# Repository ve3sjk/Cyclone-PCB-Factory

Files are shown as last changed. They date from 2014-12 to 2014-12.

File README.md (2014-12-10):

<p align="center">

<div align="center"><i>A 3D-printable (Rep-Rap alike) CNC machine, intended for PCB manufacture.</i></div>
</p>  

Read this, it's important!
===========================
If you are reading this, then you are looking at the development version of Cyclone PCB Factory.
This means files may present inconsistencies (dimensions mismatch, lack of tolerances, etc).
If you just want to build the machine, take a look at the following locations:

- **Releases: <https://github.com/carlosgs/Cyclone-PCB-Factory/releases>**
- **Documentation: <http://reprap.org/wiki/Cyclone_PCB_Factory>**

<p align="center">
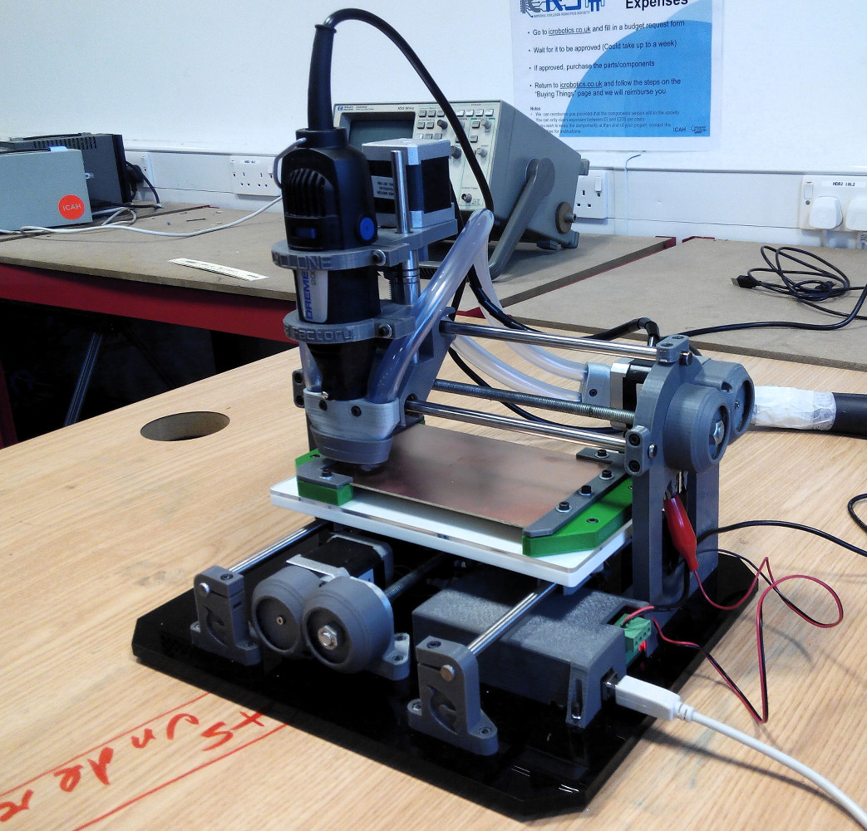
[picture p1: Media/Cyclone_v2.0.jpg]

<div align="center"><i>Cyclone v2.0</i></div>
</p>

Mail list / Forum  
-------------------
If you are interested in this project, please consider joining our mail list:  
**<https://groups.google.com/forum/#!forum/cyclone-pcb-factory>**  
Any help and feedback will be appreciated, particularly with software usage and software development :)  

Links of interest  
====================
- **[Project network](https://github.com/carlosgs/Cyclone-PCB-Factory/network)** (useful to find the latest work by collaborators)
- **[Wiki entry on RepRap.org](http://reprap.org/wiki/Cyclone_PCB_Factory)**
- **[A year of development (01/20/2014)](http://carlosgs.es/node/47)** (with information regarding the evolution of the project in 2013)

Getting the (development) source files  
========================================
Install git (http://git-scm.com/) onto your system. Then run a clone:

	git clone git://github.com/carlosgs/Cyclone-PCB-Factory.git

This will download the latest sources into a directory named 'Cyclone-PCB-Factory'.  

Version 2.0  
--  

**Cyclone PCB Factory V2.0 was developed in the department of innovation and robotics at [bq](http://www.bq.com/)**  

V2.0 addresses all the issues from the original design, and implementing improvements by yOPERO, Martin Zabojnik and others.  

* More robust design with tougher parts:
 * Better holders for the linear bearings (vibration made them slide away)
 * Reinforced nut/screw holders
* Anti-backlash mechanisms
* Improved gears with smoother edges
* Protective cover for the gears
* Attachment for a vacuum cleaner
* Better scalability (parametrized design)
* Using a [Dremel 200](http://www.dremel.com/en-us/tools/Pages/ToolDetail.aspx?pid=200+Series) as the spindle motor
* Integrated endstop holders

Future improvements:  
--  
* Endstop integration for Z (integrated probe)
* Re-implement the Z carriage, currently inherited from Cyclone V1

<p align="center">
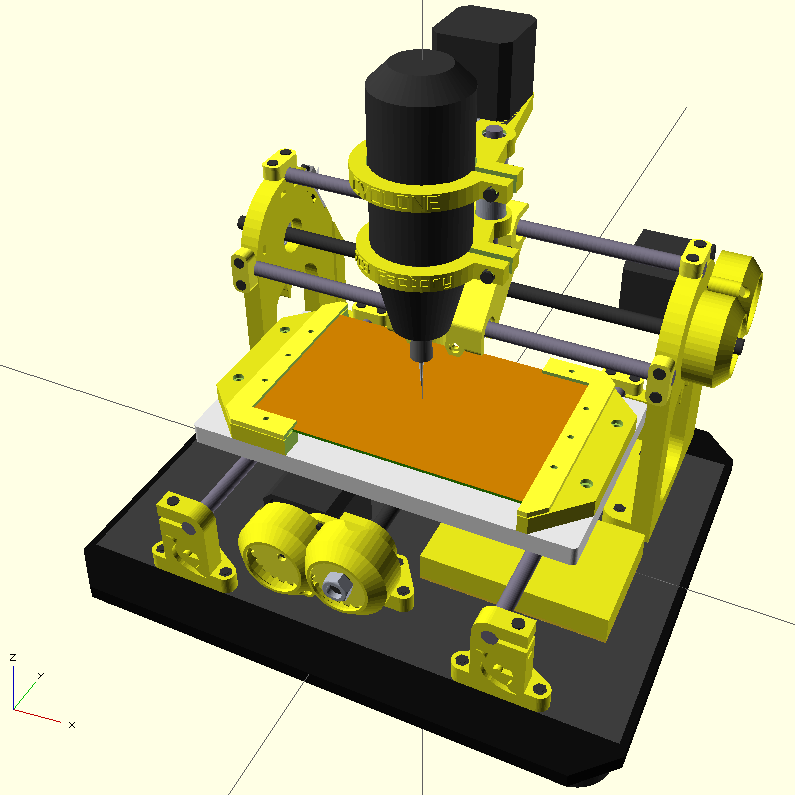
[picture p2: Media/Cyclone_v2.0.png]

<div align="center"><i>Render of Cyclone v2.0</i></div>
</p>  

<p align="center">
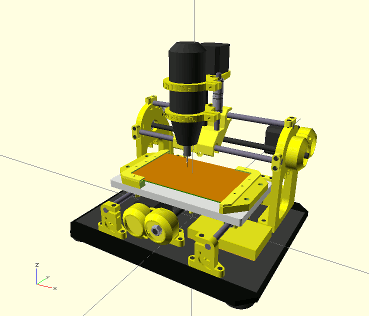
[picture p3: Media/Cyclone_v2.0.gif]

<div align="center"><i>The new design tries to be more parametrized</i></div>
</p>

Videos  
--  
- v2.0 Plexiglass "Open Source Hardware" keychain: <http://www.youtube.com/watch?v=3Kftgog89wQ>
- v2.0 Cyclone Logo in PCB (October 2014): <http://www.youtube.com/watch?v=_6oWuco_N8U>
- v2.0a Plexiglass Cyclone logo (August 2014): <http://www.youtube.com/watch?v=lPQlIvBf7Ak>
- v2.0a Milling wax (August 2014): <http://www.youtube.com/watch?v=drV_r_OSsi4>
- v0.9.7 Cyclone PCB factory, the process (June 2013): <http://www.youtube.com/watch?v=fKW3fwy1h0k>
- v0.9.6 Y axis concept by Yopero <http://www.youtube.com/watch?v=XzcobonQP40>  
- v0.9.5 Probing a PCB <http://www.youtube.com/watch?v=m5zXL8k5T9E>  
- v0.9.5 Milling MDF <http://www.youtube.com/watch?v=2QpxjheEjEc> and <http://www.youtube.com/watch?v=zjav0hBtmYA>  
- v0.8 Drawing test: <http://www.youtube.com/watch?v=Y-HSdE89JOM>  
- v0.7.5 XY axis test: <http://www.youtube.com/watch?v=9umlq4oHG64>  
- v0.7.5 High speed XY test: <http://www.youtube.com/watch?v=H3uYCXryj60>  

Bill of materials (obsolete, to be updated and moved to the RepRap wiki page)  
--  
Kobus' <https://docs.google.com/spreadsheet/ccc?key=0AjYcEd1WlkqCdERINEFvRk9mVTZvdXZFR0VHVjRWc2c#gid=0>  
Robsbots' <https://docs.google.com/spreadsheet/ccc?key=0AmiiQRLnjs9cdE12VDFmTHJ4N3JoTzcwbkJPb0ZLSWc#gid=0>  
Carlosgs' <https://docs.google.com/spreadsheet/ccc?key=0AsQp8IK25R4IdGk3LTdOWmpFR0Nrc0RhaVJaUC1CMUE>  

More pictures  
--  

<p align="center">
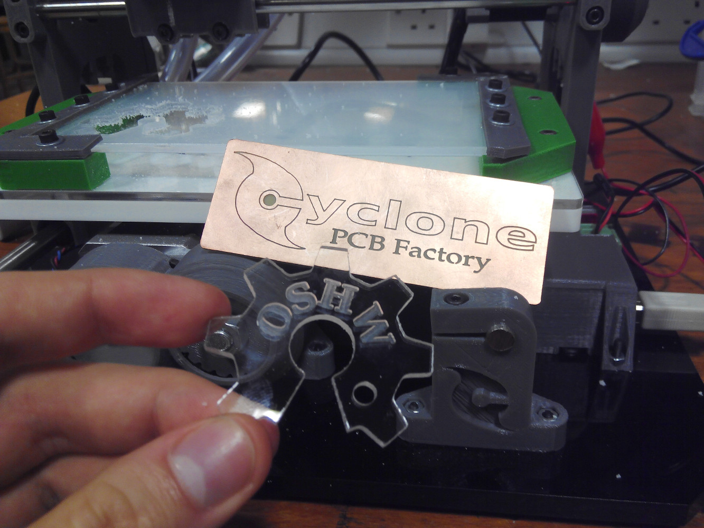
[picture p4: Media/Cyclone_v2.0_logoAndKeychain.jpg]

</p>  

<p align="center">
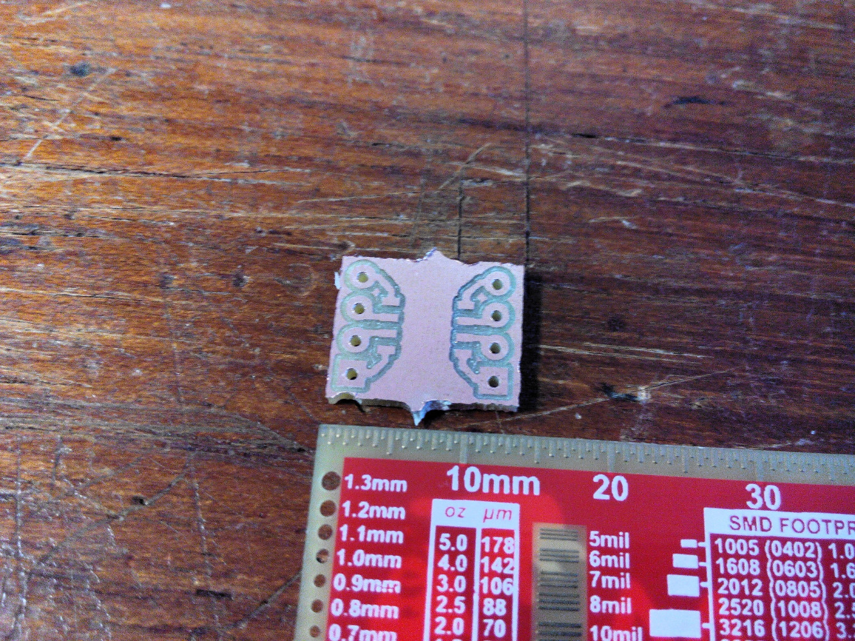
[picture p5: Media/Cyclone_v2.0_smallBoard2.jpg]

</p>  

<p align="center">
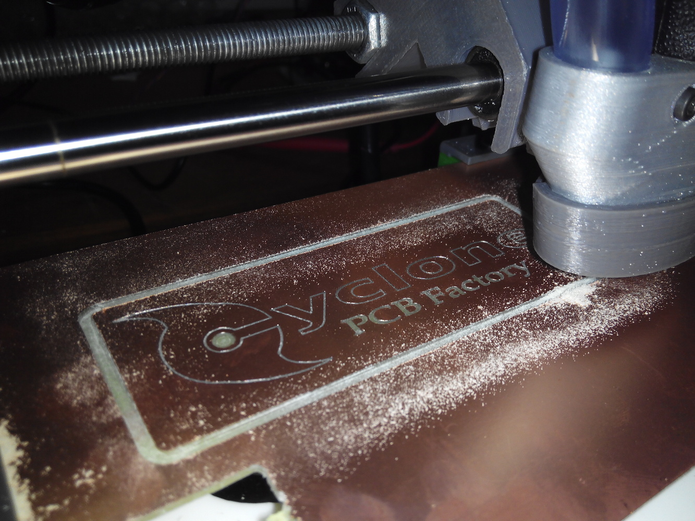
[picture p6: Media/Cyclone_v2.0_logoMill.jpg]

</p>  

<p align="center">
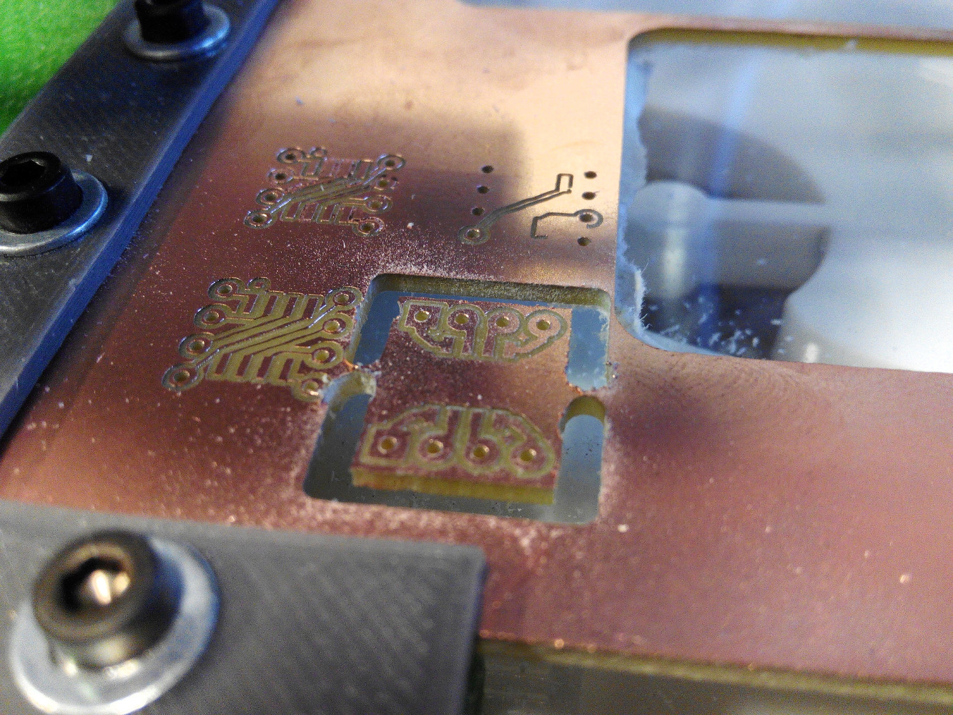
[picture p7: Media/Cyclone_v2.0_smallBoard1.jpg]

</p>  

License  
--
License: **Attribution - Share Alike - Creative Commons (<http://creativecommons.org/licenses/by-sa/3.0/>)**  

Authors:  
--
**Carlos García Saura (Carlosgs <http://carlosgs.es>)** is the original author of V2.0.  
**Many other people keeps contributing to the project (check "most active posters" at <https://groups.google.com/forum/#!aboutgroup/cyclone-pcb-factory>).**  

Special thanks  
--  
- Plenty of feedback from **Pedro de Oro**, **Alberto Valero**, **Alberto Mendez** (and **Obijuan**, **Pacle**, **Jesus**, **Ana**, **Santi**, **Antonio**, **Jose**... :-P) at the _department of innovation and robotics at [bq](http://www.bq.com/)_. **Cyclone is much more user-friendly thanks to you!**
- Z axis concepts by **Quim Borras** and the spindle motor holder by **Misan** were really useful!! Also, **Diego Viejo**'s machine was of great inspiration for the Z axis (<https://plus.google.com/u/0/photos/113930344830086538817/albums/5868944432651911713?authkey=CLDJgdehlN773gE>) **Thank you all!!**  
- This design woudn't have been possible without the encouragement of the **Panda CNC community** (<https://plus.google.com/u/0/communities/102402711800402614517>)  
- Also, thanks to **Juan González-Gómez (Obijuan <http://iearobotics.com>)** for naming the machine Cyclone :)  

Derived from / we have used / inspirational  
--
- "Linear actuator concept for CNC machines" by **Carlosgs** (<http://www.thingiverse.com/thing:45103>)  
- "Obiscad library" by **Obijuan** (<https://github.com/Obijuan/obiscad>)  
- "Minimal footprint friction-fit LM8UU holder" by **thantik** (<http://www.thingiverse.com/thing:23041>)  
- "Spindle mount for ShapeOko" by **Misan** (<http://www.thingiverse.com/thing:26740>)  
- "Carro Z para Cyclone CNC mill intended for PCB" by **Quim** (<http://www.thingiverse.com/thing:80718>)  
- "Write.scad (and DXF fonts)" by **HarlanDMii** (<http://www.thingiverse.com/thing:16193>)  
- "PCB Machining Vise" by **Forgetful_Guy** (<http://www.thingiverse.com/thing:63578>)  

Credit for the ideas used  
--  
The origin of Cyclone took place while I (carlosgs) was inside the **Panda CNC** community (<https://plus.google.com/u/0/communities/102402711800402614517>). This is from December 2012 to mid-February 2013.  
Here is the credit for the ideas that were used:  

* _Let's design a 3D-printable CNC for PCB milling, it will be named Panda:_ **Guillermo Welch** (mid-December, via Google Talk)  
* _X carriage rod distribution:_ **César Augusto Fernández Cano** claims Cyclone's X axis is a derivate of his concept: <https://plus.google.com/u/0/111421387442355054591/posts/QrfYtEuZBaj>  
* _100x160mm workspace:_ **David Martin** <https://dl.dropboxusercontent.com/u/16122275/PandaCNC_credit/workplace_size.png>  
* _Using gears to drive the X-Y axes:_ **Guillermo Welch** <https://plus.google.com/u/0/101232926728463427403/posts/QjZGNcWcgGg>  
* _Regarding the woodbase:_ **Guillermo Welch** always contemplated the possibility of attaching the machine (optionally) to a woodbase. I decided to use the base as a main structural part instead. See <https://dl.dropboxusercontent.com/u/16122275/PandaCNC_credit/woodbase.png> (screenshot from <https://plus.google.com/u/0/113437723819360223498/posts/8LDCSSVWqCS>)  
* _List of CNC endmill types:_ **David Martin** <https://dl.dropboxusercontent.com/u/16122275/PandaCNC_credit/cnc_endmill_types.png>  

Please note I have taken screenshots of the post that are on the closed G+ Panda community (<https://plus.google.com/u/0/communities/116318709564872967169>). You can register and see by yourself.  

**All other development present on Cyclone has nothing to do with Panda and is not related to the Panda project.**  

Disclaimer  
--
This hardware/software is provided "as is", and you use the hardware/software at your own risk. Under no circumstances shall any author be liable for direct, indirect, special, incidental, or consequential damages resulting from the use, misuse, or inability to use this hardware/software, even if the authors have been advised of the possibility of such damages.

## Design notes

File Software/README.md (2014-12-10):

Software for Cyclone-PCB-Factory  
===================

The original python scripts were only a proof of concept: the lack of GUI was a big drawback.  

Some alternatives were suggested, and two of them have been made by developers inside the group. Kobus Du Toit and Patrick Knöbel have worked on two different alternatives that simplify the task of Z probing by making it more visual and intuitive for the end users:  

**UPDATE: A modification of CNC-Gcode-Controller (pre-configured with Cyclone v2.0 parameters) can be downloaded from** <https://github.com/carlosgs/cncgcodecontroller/blob/master/CNC-GCode-Controller_libs.jar?raw=true>  

* [Kobus's GUI](https://www.dropbox.com/sh/k7p896n0upv29u1/1T_lcIZDnH/prototypeGui2) ([forum](https://groups.google.com/forum/#!msg/cyclone-pcb-factory/S3m1baPzwRk/DtyngGGJmBoJ)) and [Patrick Knöbel's gcode postprocessor](https://github.com/pknoe3lh/cncgcodecontroller/releases) ([forum](https://groups.google.com/forum/#!msg/cyclone-pcb-factory/ToTGIpXWUmA/gyQMDqDOXfUJ)):



* [Python scripts by Carlosgs](PythonScripts/):



Disclaimer  
--
This hardware/software is provided "as is", and you use the hardware/software at your own risk. Under nocircumstances shall any author be liable for direct, indirect, special, incidental, or consequential damages resulting from the use, misuse, or inability to use this hardware/software, even if the authors have been advised of the possibility of such damages.

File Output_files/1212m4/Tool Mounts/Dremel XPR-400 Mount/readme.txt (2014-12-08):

these file are in development to mount and xpr-400 series dremel tool. Sliced for Replicator 2x Left extruder, 232c, 130c hbp, 80mm/sec. Tested files were printed on mirror glass plate. Files include raft and manual support structure when needed.

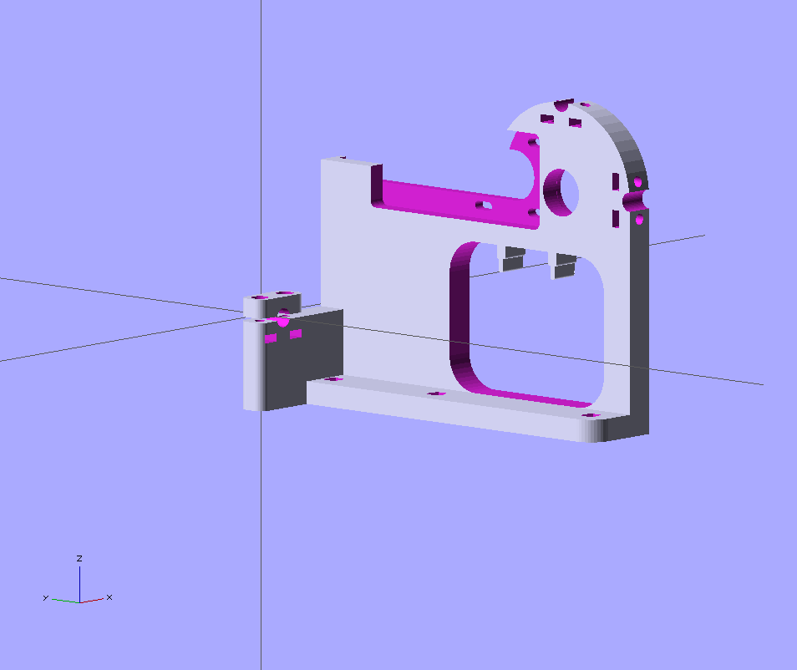
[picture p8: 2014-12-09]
Hardware/CYCLONE_2/Source_files/xRightFrame-180offset.png

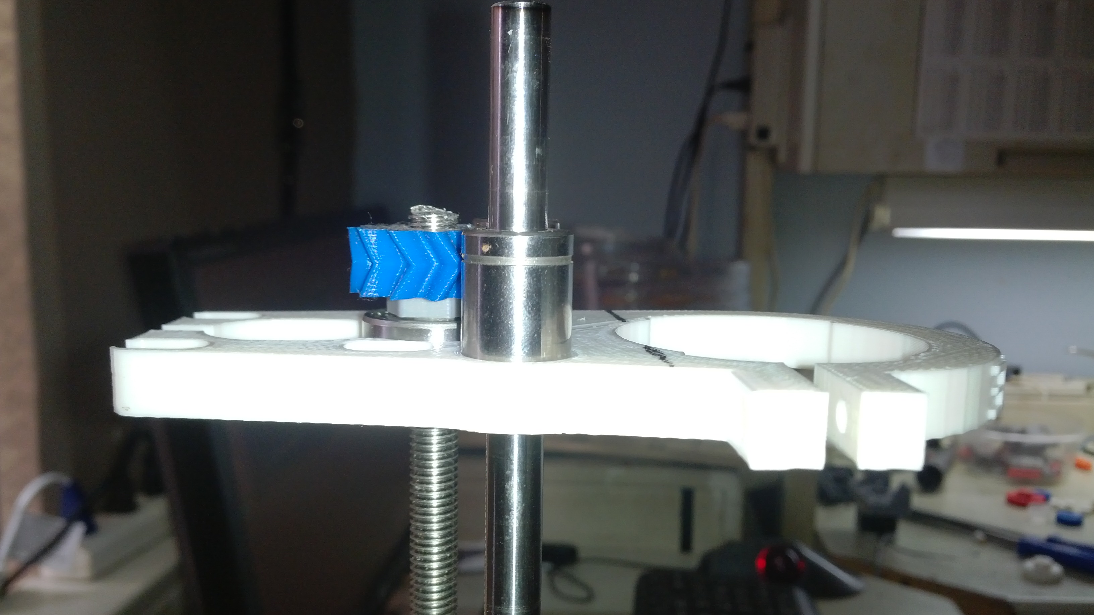
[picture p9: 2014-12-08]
Output_files/1212m4/dev pics/2014-12-06 12.53.30.jpg

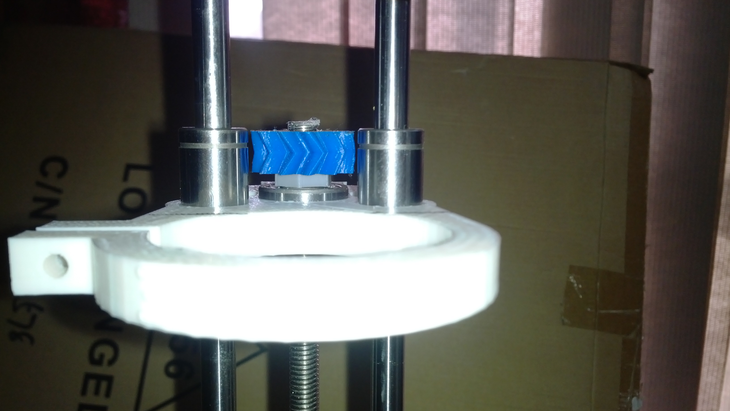
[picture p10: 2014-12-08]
Output_files/1212m4/dev pics/2014-12-06 12.53.17.jpg

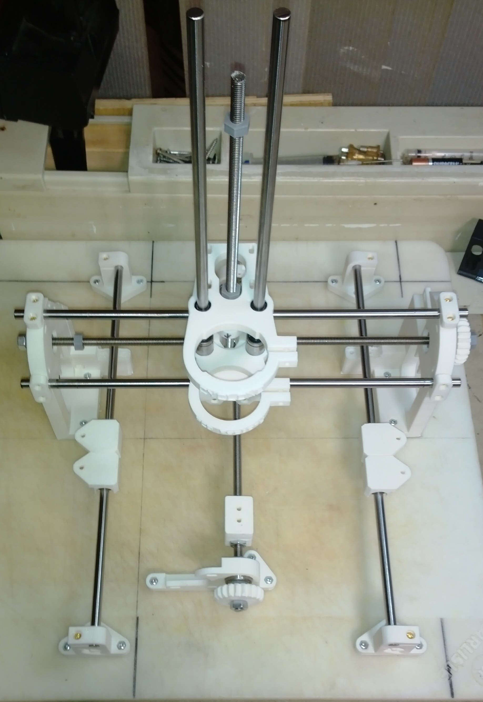
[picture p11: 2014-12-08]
Output_files/1212m4/dev pics/2014-12-06 17.03.14.jpg

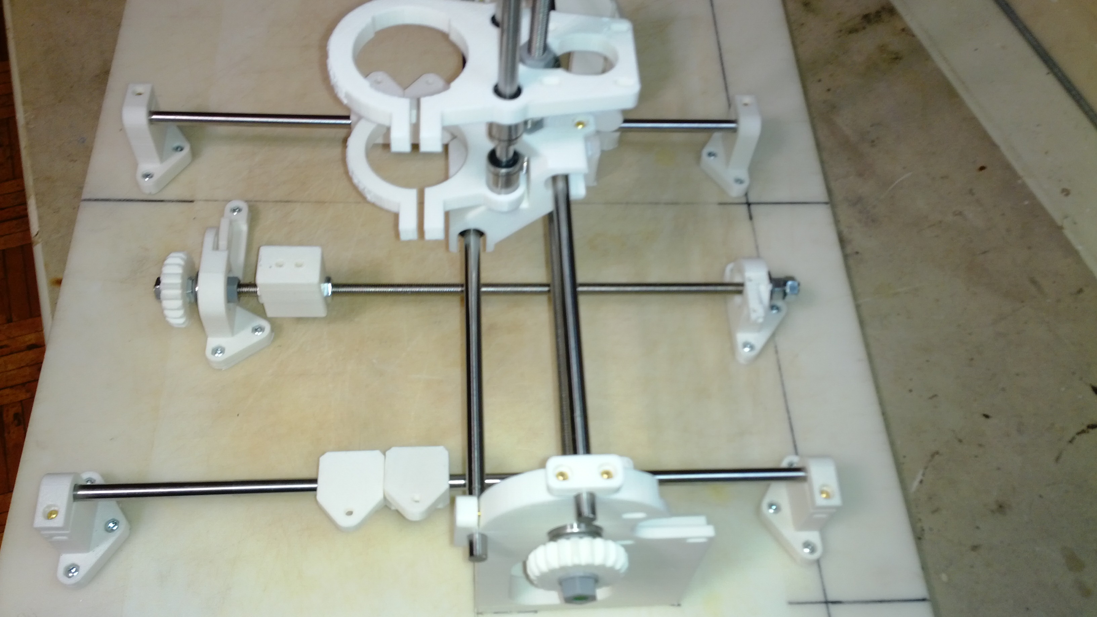
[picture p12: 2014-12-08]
Output_files/1212m4/dev pics/2014-12-06 17.04.43.jpg

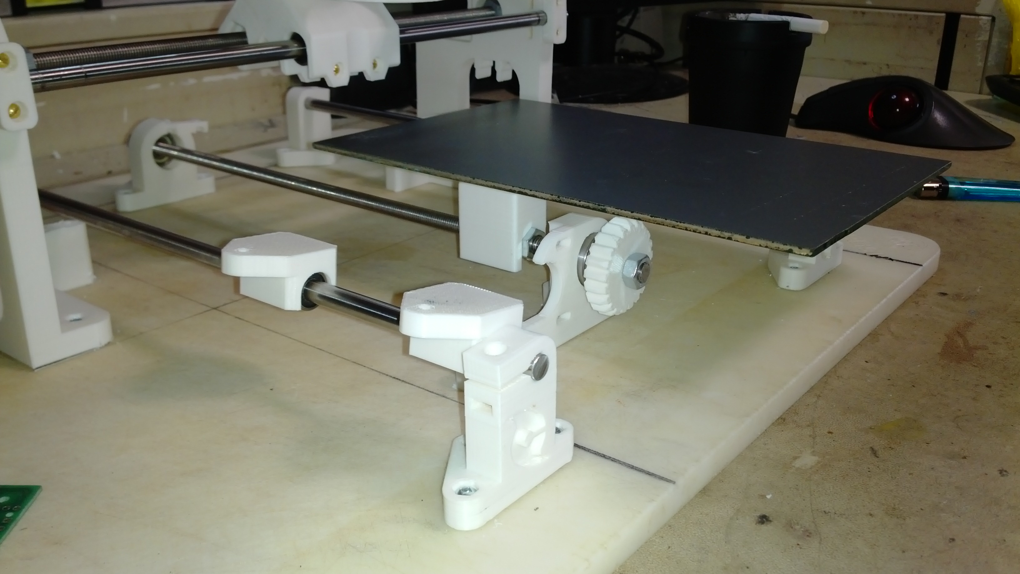
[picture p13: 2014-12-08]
Output_files/1212m4/dev pics/2014-12-06 17.22.15.jpg

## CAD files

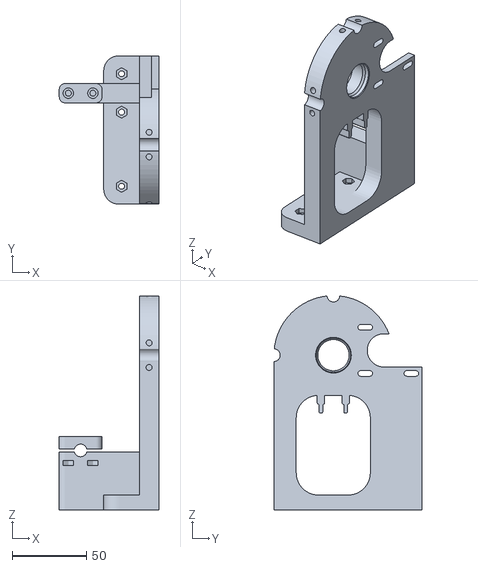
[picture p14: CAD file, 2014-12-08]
Output_files/1212m4/stl/xframeRight.stl
66.9 x 99.6 x 143.7

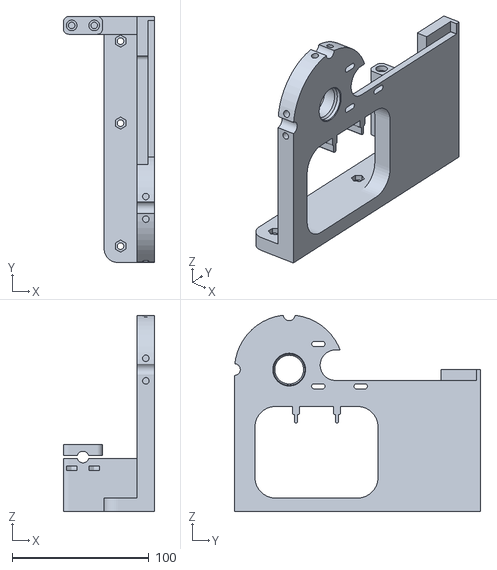
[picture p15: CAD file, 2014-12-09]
Output_files/1212m4/stl/xframesCenterY/rightframe180.stl
66.9 x 180.0 x 143.7

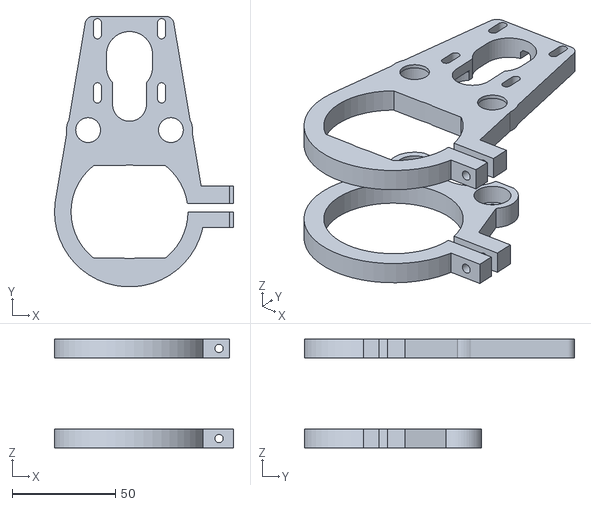
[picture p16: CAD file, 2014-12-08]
Output_files/1212m4/Tool Mounts/Dremel XPR-400 Mount/stl/dremel.stl
86.5 x 130.7 x 52.5

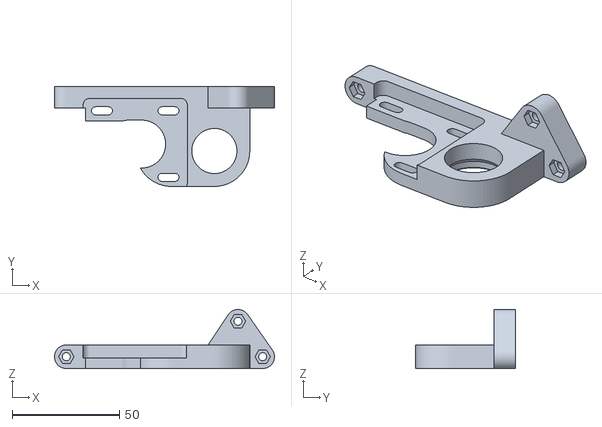
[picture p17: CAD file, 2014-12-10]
Output_files/Cycl_YfrontFrame.stl
102.5 x 46.5 x 27.5

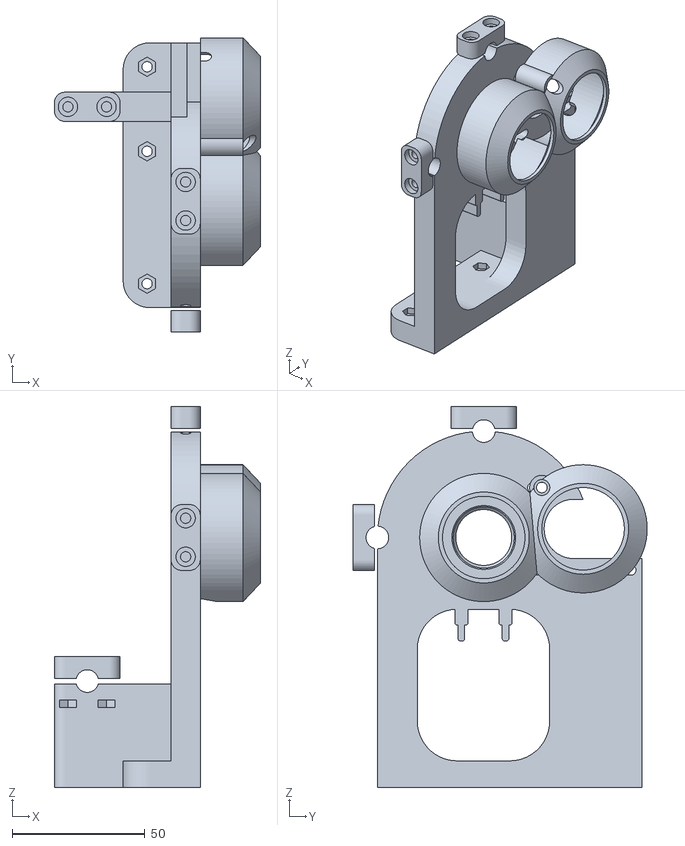
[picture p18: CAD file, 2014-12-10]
Output_files/ShorterVersion/Cyclone_XleftFrame.stl
77.6 x 110.7 x 143.2

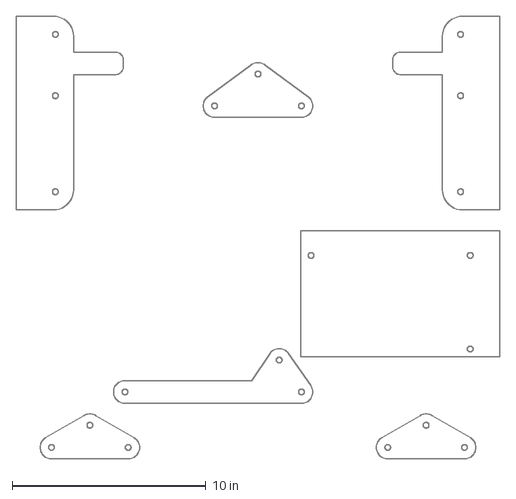
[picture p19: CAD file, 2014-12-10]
Output_files/templates/Cyclone_base_template.dxf
25.0 x 22.9 in

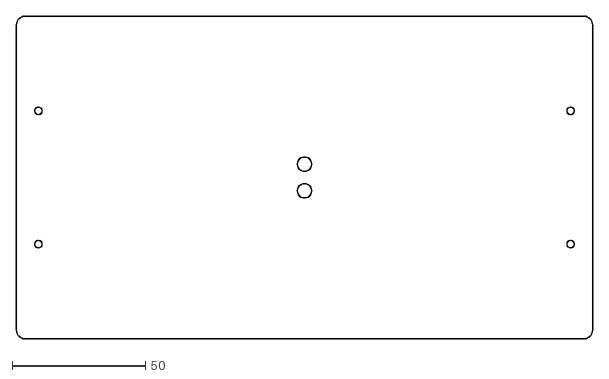
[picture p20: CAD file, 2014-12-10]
Output_files/templates/laserCut/Cyclone_workbed_3mm.dxf
216.0 x 121.0

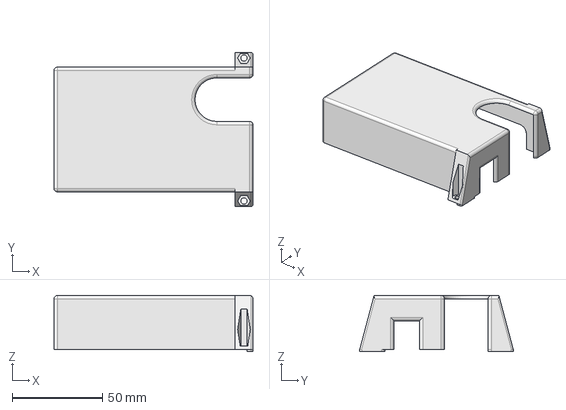
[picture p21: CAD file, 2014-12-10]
Source_files/Cycl_Electronic_case.fcstd
110.0 x 85.0 x 31.0 mm

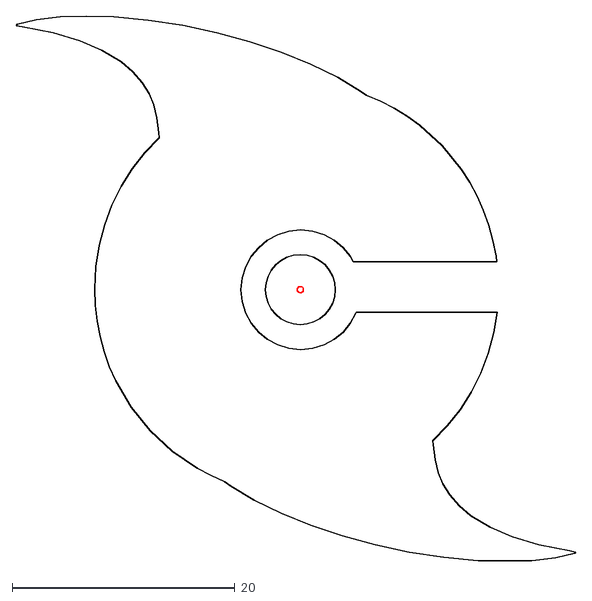
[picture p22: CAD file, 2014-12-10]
Source_files/dxf/CycloneLogo.dxf
50.2 x 48.8

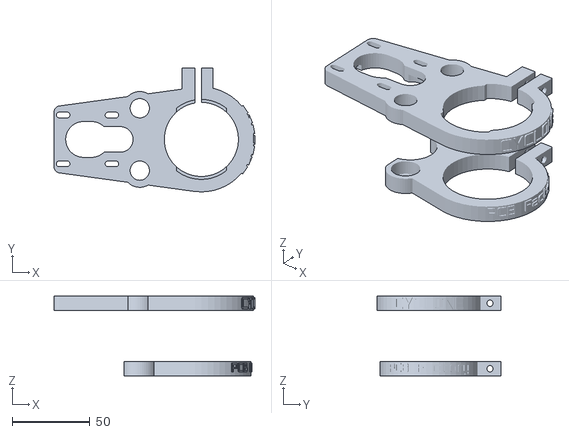
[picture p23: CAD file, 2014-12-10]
Source_files/Inherited_files/stl/Cycl_Zcarriage.stl
128.9 x 79.4 x 51.0

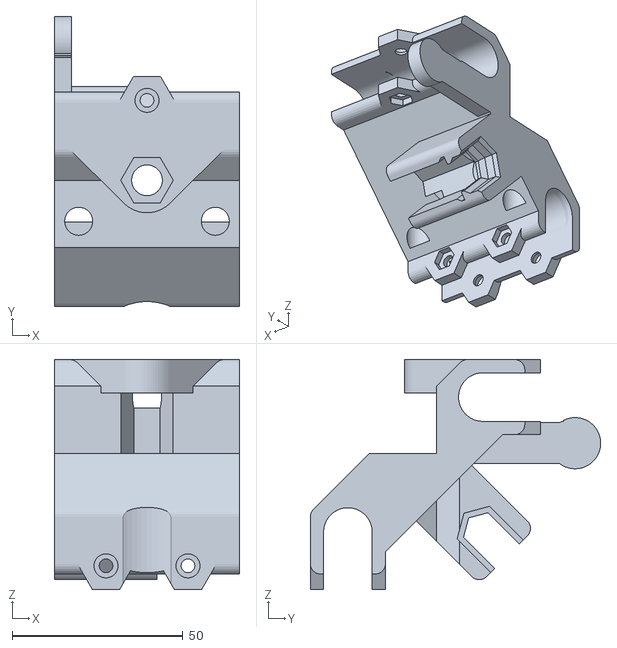
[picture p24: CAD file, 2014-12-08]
Output_files/1212m4/stl/xcarrage.stl
54.2 x 85.0 x 67.3

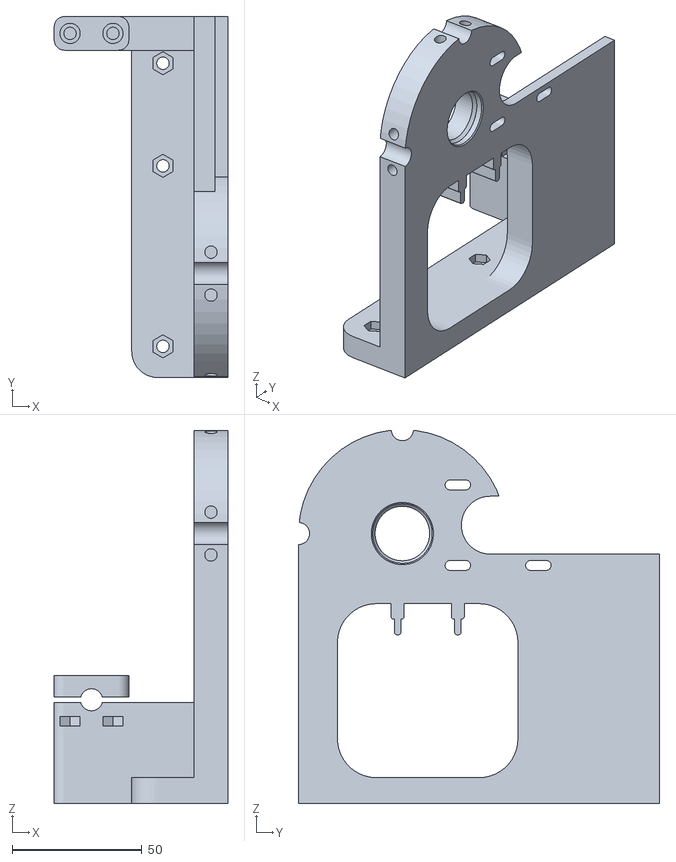
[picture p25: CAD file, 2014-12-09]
Output_files/1212m4/stl/xframesCenterY/XleftFrame.stl
66.9 x 139.0 x 143.7

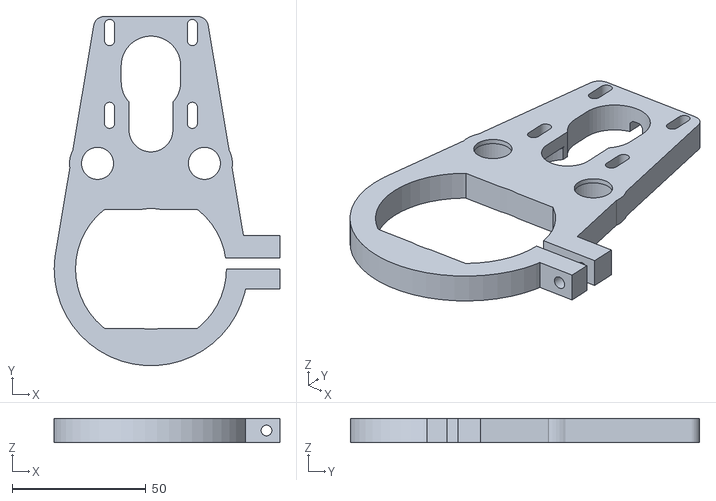
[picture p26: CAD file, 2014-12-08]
Output_files/1212m4/Tool Mounts/Dremel XPR-400 Mount/stl/top.stl
84.5 x 130.7 x 9.00

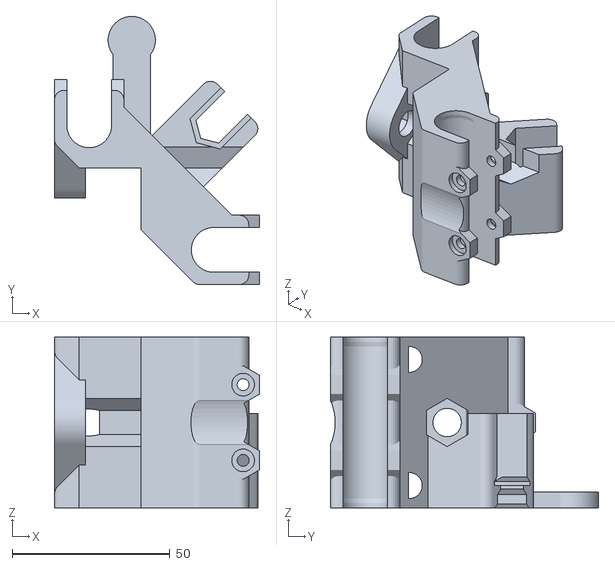
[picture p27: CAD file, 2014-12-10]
Output_files/Cycl_Xcarriage.stl
65.0 x 85.0 x 54.2

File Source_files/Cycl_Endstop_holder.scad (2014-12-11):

// This file is part of Cyclone PCB Factory: an open-source 3D printable CNC machine for PCB manufacture
// http://reprap.org/wiki/Cyclone_PCB_Factory
// Original author: Carlosgs (http://carlosgs.es)
// License: CC BY-SA 4.0 (Attribution-ShareAlike 4.0 International, http://creativecommons.org/licenses/by-sa/4.0/)
// Designed with http://www.openscad.org/


// Original Endstop Board Holder
// Fits Endstop Assembly ?

// moved to separate module to accomodate differnt endstop switches

// TO DO:
//Create endstop for Highly VS-15 Med lengh Roller Swithes
//Should be able to select endstop type by model in config. h
// File when completed.

module endstop_holder(holes=false, plasticColor="blue", shortNuts=false) {
	    

        boardX = boardX_size;

	boardY = boardY_size;

	boardZ = boardZ_size;

	

	holderX = holderX_size;

	holderY = holderY_size;

	holderZ = holderZ_size;

	screwWallSep = endstop_screwWallSep; 

        screwsize = endstop_holder_screwsize;   

    
	
	if(holes) {
		translate([0,0,-boardZ]) {
			// PCB
			cube([boardX,boardY,boardZ+10]);
			// Endstop pins
			translate([6.2,6.5,-3])
				cube([13.5,5,3]);
			// Connector pins
			translate([26.7,3.5,-3])
				cube([3,7.8,3]);
		}
		translate([0,screwWallSep,3]) {
			translate([3.7,0,0])
				rotate([90,0,0])
					hole_for_screw(size=3,length=15,nutDepth=shortNuts?5:0,nutAddedLen=shortNuts?0:5,captiveLen=10,rot=90);
			translate([22.7,0,0])
				rotate([90,0,0])
					hole_for_screw(size=3,length=15,nutDepth=shortNuts?5:0,nutAddedLen=shortNuts?0:5,captiveLen=10,rot=90);
		}
	} else {
		color(plasticColor) translate([holderX/2,holderY/2,-holderZ/2-boardZ])
			bcube([holderX,holderY,holderZ], cr=2, cres=4);
		// PCB
		color("lightgrey") translate([0,0,-boardZ])
			%cube([boardX,boardY,boardZ]);
		// Endstop
		color("grey") translate([6.8,0,0])
			%cube([12.8,6.5,6.3]);
		color("lightgrey") translate([6.8+12.8-1,0,0])
			rotate([0,0,180+15])
				%cube([12.8,0.2,6.3]);
		// Screws
		translate([0,screwWallSep,3]) {
			translate([3.7,0,0])
				rotate([90,0,0])
					screw_and_nut(size=3,length=10,nutDepth=0, rot=90, echoPart=true);
			translate([22.7,0,0])
				rotate([90,0,0])
					screw_and_nut(size=3,length=10,nutDepth=0, rot=90, echoPart=true);
		}
	}
    }

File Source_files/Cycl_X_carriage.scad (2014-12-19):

// This file is part of Cyclone PCB Factory: an open-source 3D printable CNC machine for PCB manufacture
// http://reprap.org/wiki/Cyclone_PCB_Factory
// Original author: Carlosgs (http://carlosgs.es)
// License: CC BY-SA 4.0 (Attribution-ShareAlike 4.0 International, http://creativecommons.org/licenses/by-sa/4.0/)
// Designed with http://www.openscad.org/

rod_nut_len = 0.8*axes_Xthreaded_rodD;
washer_D = X_backlash_washer_D;
washer_thickness = X_backlash_washer_thickness;
holderExtension = 10;

use <libs/linear_bearing.scad>
use <libs/standard_parts.scad>
module Cyclone_X_carriage() {
	linearBearingLength = linearBearing_L(X_linearBearingModel);
	linearBearingDiameter = linearBearing_D(X_linearBearingModel);
	
	// Correction is needed to account for 3D printer tolerances
	axes_effective_Xsmooth_separation = axes_Xsmooth_separation-axes_Xsmooth_separation_tolerance;
	
	sideExtensions = linearBearingDiameter/3+2;
	
	ZrodHolderLength = 30;
	
	screwSize = X_carriage_screwSize;
	screwLength = linearBearingDiameter+sideExtensions;
	screwAditionalLength = 2;
	
	screwExtension = screwSize*1.2;
	
	linearBearingLengthExtension = 6+max(axes_Zsmooth_rodD+axes_Zsmooth_separation-2*linearBearingLength-X_linearBearingSeparation, X_linearBearingSeparation);
	
	dimX = 2*linearBearingLength+linearBearingLengthExtension;
	
	module Cyclone_XsubPart_ZnutHolder(holes=false) {
		rodTolerance = X_threaded_rod_Tolerance;
		rodSize = Z_threaded_rodNutSize; // M3, M4, etc (integers only)
		dimZ = rod_nut_len+3; // Nut holder thickness
		
		if(!holes) {
			rotate([0,180,0])
				hull() {
					cylinder(r=axes_Zthreaded_rodD+1, h=dimZ);
					translate([0,-axes_Zreference_posY-axes_ZthreadedReference_posY+axes_effective_Xsmooth_separation,dimZ/2])
						cube([dimX,0.1,dimZ], center=true);
				}
		} else {
			// Hole for the main Z nut
			translate([0,0,0.1]) rotate([90,0,0]) hole_for_nut(size=rodSize,nutAddedLen=0,captiveLen=0, tolerance=0.2);
			// Hole for the Z threaded rod
			translate([0,0,-axes_effective_Xsmooth_separation+dimZ])
				rotate([90,0,0]) standard_rod(diam=axes_Zthreaded_rodD+rodTolerance, length=axes_effective_Xsmooth_separation*2, threaded=true, renderPart=true, center=true);
			translate([0,0,-dimZ-0.01]) rotate([180,0,0]) cylinder(r=axes_Zthreaded_rodD*0.9, h=axes_effective_Xsmooth_separation+dimZ*2, $fn=6);
		}
	}
	
	module Cyclone_XsubPart_alt_nutHolder(holes=false) {
		rodTolerance = X_threaded_rod_Tolerance;
		rodSize = Z_threaded_rodNutSize; // M3, M4, etc (integers only)
		dimZ = rod_nut_len+6; // Nut holder thickness
		
		if(!holes) {
			rotate([0,180,0])
				hull() {
					cylinder(r=axes_Zthreaded_rodD+1, h=dimZ);
					translate([0,-axes_Zreference_posY-axes_ZthreadedReference_posY+axes_effective_Xsmooth_separation,dimZ/2])
						cube([dimX,0.1,dimZ], center=true);
				}
		} else {
			// Hole for the main Z nut
			translate([0,0,-3]) rotate([90,0,0]) hole_for_nut(size=rodSize,nutAddedLen=0,captiveLen=20,rot=90,tolerance=0.2);
			// Hole for the Z threaded rod
			translate([0,0,-axes_effective_Xsmooth_separation+dimZ])
				rotate([90,0,0]) standard_rod(diam=axes_Zthreaded_rodD+rodTolerance, length=axes_effective_Xsmooth_separation*2, threaded=true, renderPart=true, center=true);
			translate([0,0,-dimZ-0.01]) rotate([180,0,0]) cylinder(r=axes_Zthreaded_rodD*0.9, h=axes_effective_Xsmooth_separation+dimZ*2, $fn=6);
		}
	}
	
	module Cyclone_XsubPart_XnutHolder(holes=false) {
		rodSize = X_threaded_rodNutSize; // M3, M4, etc (integers only)		
		
		armWidth = axes_Xthreaded_rodD*2+6;
		
		if(!holes) {
			// Main shape
			translate([X_backlash_armThickness/2,0,-axes_effective_Xsmooth_separation/2+holderExtension])
				rotate([0,90,0]) bcube([axes_effective_Xsmooth_separation,armWidth,X_backlash_armThickness], cr=3,cres=10);
			*translate([32/2,0,0])
				rotate([180,0,0]) rotate([0,0,90]) Cyclone_YsubPart_nutHolder();
		} else {
			if(draw_references) %frame();
			translate([-rod_nut_len/2+1,0,0]) rotate([0,0,-90]) rotate([180,0,0]) {
				// Hole for the main nut
				hull() {
					rotate([0,180,0]) hole_for_nut(size=rodSize,nutAddedLen=0,captiveLen=axes_Xthreaded_rodD*3,rot=90,tolerance=0.1);
					translate([0,-3.25,0])
						rotate([0,180,0]) hole_for_nut(size=rodSize-2,nutAddedLen=0,captiveLen=axes_Xthreaded_rodD*3,rot=90,tolerance=0.1);
				}
				translate([0,3,0])
					hull() {
						rotate([0,180,0]) hole_for_nut(size=rodSize,nutAddedLen=0,captiveLen=axes_Xthreaded_rodD*3,rot=90,tolerance=0.1);
						translate([0,4,0])
							rotate([0,180,0]) hole_for_nut(size=rodSize+2,nutAddedLen=0,captiveLen=axes_Xthreaded_rodD*3,rot=90,tolerance=0.1);
					}
				// Hole for the sliding nut
				translate([0,-rod_nut_len-3-washer_thickness/2,0]) hull() {
					rotate([0,180,0]) hole_for_nut(size=rodSize,nutAddedLen=X_backlash_armThickness,captiveLen=axes_Xthreaded_rodD*3,rot=90,tolerance=0.3);
					translate([0,-2.25,0])
						rotate([0,180,0]) hole_for_nut(size=rodSize,nutAddedLen=X_backlash_armThickness,captiveLen=axes_Xthreaded_rodD*3,rot=90,tolerance=0.3);
				}
				// Hole for the rod
				rotate([0,180,0])hole_for_nut(size=rodSize-2,nutAddedLen=X_backlash_armThickness,captiveLen=axes_Xthreaded_rodD*3,rot=90,tolerance=0.1);
			}
			// Hole for the washer
			translate([rod_nut_len/2+3+1,0,0]) rotate([0,0,-90]) rotate([180,0,0])
				hull() {
					hull() {
						washer_single(diam=washer_D, thickness=washer_thickness, renderPart=true, tolerance=0.3);
						translate([0,0,-holderExtension*2])
							washer_single(diam=washer_D, thickness=washer_thickness, renderPart=true, tolerance=0.3);
					}
					hull() {
						washer_single(diam=rodSize, thickness=4.5+washer_thickness, renderPart=true, tolerance=0.3);
						translate([0,0,-holderExtension*2])
							washer_single(diam=rodSize, thickness=4.5+washer_thickness, renderPart=true, tolerance=0.3);
					}
				}
			*translate([-0.01+rod_nut_len/2+6,0,0])
				hull() {
					rotate([0,0,-90]) hole_for_nut(size=rodSize,nutAddedLen=-1.25,captiveLen=axes_Xthreaded_rodD*3,rot=90,tolerance=0.1);
					translate([2,0,0])
						rotate([0,0,-90]) hole_for_nut(size=rodSize-2,nutAddedLen=0,captiveLen=axes_Xthreaded_rodD*3,rot=90,tolerance=0.1);
				}
			*translate([X_backlash_armThickness+0.01,0,0])
				rotate([0,0,-90]) hole_for_nut(size=rodSize-2,nutAddedLen=X_backlash_armThickness,captiveLen=axes_Xthreaded_rodD*3,rot=90,tolerance=0.1);
		}
	}
	
	module Cyclone_XsubPart_XnutHolder_SINGLE_NUT(holes=false) {
		
		rodSize = X_threaded_rodNutSize; // M3, M4, etc (integers only)
		washer_D = X_backlash_washer_D;
		
		armWidth = axes_Xthreaded_rodD*2+5;
		
		X_backlash_armThickness = rod_nut_len*2;
		
		if(!holes) {
			translate([X_backlash_armThickness/2,0,-axes_effective_Xsmooth_separation/2+washer_D/2])
				rotate([0,90,0]) bcube([axes_effective_Xsmooth_separation,armWidth,X_backlash_armThickness], cr=3,cres=10);
		} else {
			if(draw_references) %frame();
			translate([-0.01+rod_nut_len/2+6,0,0])
				hull() {
					rotate([0,0,-90]) hole_for_nut(size=8,nutAddedLen=-1.25,captiveLen=axes_Xthreaded_rodD*3,rot=90,tolerance=0.1);
					translate([2,0,0])
						rotate([0,0,-90]) hole_for_nut(size=6,nutAddedLen=0,captiveLen=axes_Xthreaded_rodD*3,rot=90,tolerance=0.1);
				}
			translate([X_backlash_armThickness+0.01,0,0])
				rotate([0,0,-90]) hole_for_nut(size=6,nutAddedLen=X_backlash_armThickness,captiveLen=axes_Xthreaded_rodD*3,rot=90,tolerance=0.1);
		}
	}
	
	module Cyclone_XsubPart_XendstopBumper() {
		XendBumper_x = 5;
		XendBumper_y = 53;
		XendBumper_z = 12;
		XendBumper_D = 15;
		translate([XendBumper_x/2, XendBumper_y/2-axes_Xsmooth_separation/2, -XendBumper_z/2-linearBearingDiameter/2]) {
				rotate([0,90,0]) bcube([XendBumper_z,XendBumper_y,XendBumper_x], cr=XendBumper_z/2-0.01, cres=10);
				translate([0,XendBumper_y/2-XendBumper_z/2,0])
					rotate([0,90,0]) cylinder(r=XendBumper_D/2, h=XendBumper_x, center=true);
					//rotate([0,90,0]) bcube([XendBumper_z,XendBumper_y,XendBumper_x], cr=XendBumper_z/2-0.01, cres=10);
			}
	}
	
	color(color_movingPart) difference() {
		// Main shape
		union() {
			hull() {
				rotate([0,90,0]) 
					bcube([linearBearingDiameter,linearBearingDiameter+sideExtensions, dimX], cr=3, cres=5);
				translate([0,axes_effective_Xsmooth_separation,axes_effective_Xsmooth_separation])
					rotate([0,90,0]) 
						bcube([linearBearingDiameter+sideExtensions,linearBearingDiameter, dimX], cr=3, cres=5);
			}
			translate([0,0,-screwExtension/2])
				rotate([0,90,0])
					bcube([linearBearingDiameter+screwExtension,linearBearingDiameter+sideExtensions, dimX], cr=3, cres=5);
			translate([0,axes_effective_Xsmooth_separation+screwExtension/2,axes_effective_Xsmooth_separation])
				rotate([0,90,0]) 
					bcube([linearBearingDiameter+sideExtensions,linearBearingDiameter+screwExtension, dimX], cr=3, cres=5);
			// Bottom right screw
			translate([-linearBearingLength/2-X_linearBearingSeparation/2,0,-linearBearingDiameter/2-screwExtension/2])
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

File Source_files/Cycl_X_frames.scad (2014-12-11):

// This file is part of Cyclone PCB Factory: an open-source 3D printable CNC machine for PCB manufacture
// http://reprap.org/wiki/Cyclone_PCB_Factory
// Original author: Carlosgs (http://carlosgs.es)
// License: CC BY-SA 4.0 (Attribution-ShareAlike 4.0 International, http://creativecommons.org/licenses/by-sa/4.0/)
// Designed with http://www.openscad.org/

X_motorModel = Nema17;	
Xmotor_sideLen = lookup(NemaSideSize, X_motorModel); //42.20;
axes_XgearRatio = X_motorGearRatio/X_rodGearRatio; // Number of tooth (motor/rod)

module Cyclone_X_leftFrame() {
	scale([-1,1,1]) Cyclone_X_rightFrame(isLeft=true);
}

include <libs/MCAD/stepper.scad>
module Cyclone_X_rightFrame(isLeft=false) {

	footThickness = X_frame_footThickness;
	corner_radius = X_frame_corner_radius;
	frameFrontalThickness = X_frame_FrontalThickness;
	
	footScrewSize = X_Frame_footScrewSize;
	rodScrewSize = X_Frame_rodScrewSize;
	
	motorWallSeparation = X_motorWallSeparation;
	motorRotatedOffset = X_motorRotatedOffset;
	gearWallSeparation = X_gearWallSeparation;
	
	partThickness = X_frames_additional_thickness+rodScrewSize*2;
	
	dimX = partThickness;
	dimY = max(-axes_Xreference_posY,axes_Xsmooth_separation+axes_XgearSeparation*cos(motorRotatedOffset)+Xmotor_sideLen/2+1.6);
	dimZ = axes_Yreference_height+axes_Xreference_height+axes_Xsmooth_separation;
	
	footSeparation = footScrewSize*3;
	footWidth = dimX+2*footSeparation;
	
	rodNutSize = X_threaded_rodNutSize;
	rod_nut_len = METRIC_NUT_THICKNESS[rodNutSize];
	nut_separation = rod_nut_len/2;
  //rod_nut_len = 0.8*axes_Xthreaded_rodD;
	
	module Cyclone_XsubPart_gearCover() {
		margin = gearCover_margin;
		rodGearAddedMargin = rodGearAddedgearCover_margin;
		effectiveXgearSeparation = axes_XgearSeparation+0.5;
		wallThickness = gearCover_wallThickness;
		screwHeadSpaceHeight = gearCover_screwHeadSpaceHeight;
		screwHeadSpaceDiam = gearCover_screwHeadSpaceDiam;
		coverHeight = gearCoverHeight;
		coverExtraHeight = gearCoverExtraHeight;
		coverExtraRadius = gearCoverExtraRadius;
		nema_screw_separation = lookup(NemaDistanceBetweenMountingHoles, X_motorModel);
		truncationAngle = gearCover_truncationAngle;
	
		motorGearRadius = axes_XgearSeparation/(1+axes_XgearRatio)+gearCover_margin;
		rodGearRadius = axes_XgearSeparation/(1+1/axes_XgearRatio)+gearCover_margin+rodGearAddedgearCover_margin;
		
		difference() {
			union() {
				// Cover for the rod gear
				rotate([0,90,0])
					cylinder(r=rodGearRadius+gearCover_wallThickness, h=coverHeight);
				translate([coverHeight,0,0])
					rotate([0,90,0])
						cylinder(r1=rodGearRadius+gearCover_wallThickness, r2=rodGearRadius+gearCover_wallThickness+coverExtraRadius, h=coverExtraHeight+gearCover_wallThickness);
				// Translate to motor position
				rotate([motorRotatedOffset,0,0]) {
					translate([0,effectiveXgearSeparation,0])
						rotate([-motorRotatedOffset,0,0]) {
							// Cover for the motor gear
							rotate([0,90,0]) cylinder(r=motorGearRadius+gearCover_wallThickness, h=coverHeight);
							translate([coverHeight,0,0])
								rotate([0,90,0]) cylinder(r1=motorGearRadius+gearCover_wallThickness, r2=motorGearRadius+gearCover_wallThickness+coverExtraRadius, h=coverExtraHeight+gearCover_wallThickness);
							// Cylinder for the support screw
							translate([0,-nema_screw_separation/2,nema_screw_separation/2])
								rotate([0,90,0]) cylinder(r=gearCover_screwHeadSpaceDiam/2+gearCover_wallThickness, h=coverHeight);
						}
				}
			}
			translate([-0.02,0,0])
				union() {
					// Truncation for avoiding collisions with Y carriage (needed for the Y gear cover)
					translate([0,-rodGearRadius/2,-rodGearRadius-0.5])
						rotate([0,90+gearCover_truncationAngle,0]) cube(rodGearRadius);
					// Hole for the rod gear
					rotate([0,90,0])
						cylinder(r=rodGearRadius, h=coverHeight);
					translate([coverHeight-0.02,0,0])
						rotate([0,90,0])
							cylinder(r1=rodGearRadius, r2=rodGearRadius+coverExtraRadius, h=coverExtraHeight);
					rotate([0,90,0])
						cylinder(r=rodGearRadius+coverExtraRadius, h=coverHeight+coverExtraHeight+gearCover_wallThickness+0.1);
					// Translate to motor position
					rotate([motorRotatedOffset,0,0]) {
						translate([0,effectiveXgearSeparation,0])
							rotate([-motorRotatedOffset,0,0]) {
								difference() {
									union() {
										// Hole for the motor gear
										rotate([0,90,0]) cylinder(r=motorGearRadius, h=coverHeight);
										translate([coverHeight-0.02,0,0])
											rotate([0,90,0]) cylinder(r1=motorGearRadius, r2=motorGearRadius+coverExtraRadius, h=coverExtraHeight);
										rotate([0,90,0]) cylinder(r=motorGearRadius+coverExtraRadius, h=coverHeight+coverExtraHeight+gearCover_wallThickness+0.1);
										// Outer hole for the support screw
										translate([0,-nema_screw_separation/2,nema_screw_separation/2])
											rotate([0,90,0]) cylinder(r=gearCover_screwHeadSpaceDiam/2, h=coverHeight+coverExtraHeight*2);
									}
									// Support screw holder
									translate([0,-nema_screw_separation/2,nema_screw_separation/2])
										rotate([0,90,0]) cylinder(r=gearCover_screwHeadSpaceDiam/2+gearCover_wallThickness, h=gearCover_wallThickness);
								}
								// Inner hole for the support screw
								translate([0,-nema_screw_separation/2,nema_screw_separation/2])
									rotate([0,90,0]) cylinder(r=(gearCover_screwHeadSpaceDiam+1)/2, h=coverHeight+0.1);
								// Holes for the other three screws
								translate([0,nema_screw_separation/2,nema_screw_separation/2])
									rotate([0,90,0]) cylinder(r=gearCover_screwHeadSpaceDiam/2, h=gearCover_screwHeadSpaceHeight/2);
								translate([gearCover_screwHeadSpaceHeight/2,nema_screw_separation/2,nema_screw_separation/2])
									rotate([0,90,0]) sphere(r=gearCover_screwHeadSpaceDiam/2);
								
								translate([0,nema_screw_separation/2,-nema_screw_separation/2])
									rotate([0,90,0]) cylinder(r=gearCover_screwHeadSpaceDiam/2, h=gearCover_screwHeadSpaceHeight/2);
								translate([gearCover_screwHeadSpaceHeight/2,nema_screw_separation/2,-nema_screw_separation/2])
									rotate([0,90,0]) sphere(r=gearCover_screwHeadSpaceDiam/2);
								
								translate([0,-nema_screw_separation/2,-nema_screw_separation/2])
									rotate([0,90,0]) cylinder(r=gearCover_screwHeadSpaceDiam/2, h=gearCover_screwHeadSpaceHeight/2);
								translate([gearCover_screwHeadSpaceHeight/2,-nema_screw_separation/2,-nema_screw_separation/2])
									rotate([0,90,0]) sphere(r=gearCover_screwHeadSpaceDiam/2);
							}
					}
				}
		}
	}
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

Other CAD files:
Output_files/ShorterVersion/Cyclone_XrightFrame.stl
Output_files/templates/Cyclone_workbed_template.dxf
Output_files/templates/laserCut/Cyclone_workbed_8mm.dxf
Source_files/dxf/oshw.dxf
Source_files/Cycl_Endstop_holder_alt.scad
Output_files/1212m4/Tool Mounts/Dremel XPR-400 Mount/stl/btm.stl
Output_files/1212m4/stl/Ylm8uuHolder.stl
Output_files/1212m4/stl/gearcover.stl
Output_files/1212m4/stl/smoothrodhold.stl
Output_files/1212m4/stl/xframeLeft.stl
Output_files/1212m4/stl/xmotgear.stl
Output_files/1212m4/stl/xrodgear.stl
Output_files/1212m4/stl/yframeback.stl
Output_files/1212m4/stl/yframefront.stl
Output_files/1212m4/stl/ygearcover.stl
Output_files/1212m4/stl/ygearrod.stl
Output_files/1212m4/stl/yleftidler.stl
Output_files/1212m4/stl/ymotgear.stl
Output_files/1212m4/stl/ynutholder.stl
Output_files/1212m4/stl/yrightidler.stl
Output_files/1212m4/stl/zcarraige.stl
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

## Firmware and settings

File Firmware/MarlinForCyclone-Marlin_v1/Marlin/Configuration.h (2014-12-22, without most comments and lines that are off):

#define CONFIGURATION_H
#define STRING_VERSION_CONFIG_H __DATE__ " " __TIME__ // build date and time
#define STRING_CONFIG_H_AUTHOR "Carlosgs" // Who made the changes.
#define SERIAL_PORT 0
#define BAUDRATE 115200
#define MOTHERBOARD 35
#define EXTRUDERS 1
#define POWER_SUPPLY 1
#define TEMP_SENSOR_0 1
#define TEMP_SENSOR_1 0
#define TEMP_SENSOR_2 0
#define TEMP_SENSOR_BED 0
#define MAX_REDUNDANT_TEMP_SENSOR_DIFF 10
#define TEMP_RESIDENCY_TIME 10  // (seconds)
#define TEMP_HYSTERESIS 3       // (degC) range of +/- temperatures considered "close" to the target one
#define TEMP_WINDOW     1       // (degC) Window around target to start the residency timer x degC early.
#define HEATER_0_MINTEMP 0 // Cyclone: Ignore thermistor
#define HEATER_1_MINTEMP 5
#define HEATER_2_MINTEMP 5
#define BED_MINTEMP 5
#define HEATER_0_MAXTEMP 275
#define HEATER_1_MAXTEMP 275
#define HEATER_2_MAXTEMP 275
#define BED_MAXTEMP 150
#define BANG_MAX 255 // limits current to nozzle while in bang-bang mode; 255=full current
#define PID_MAX 255 // limits current to nozzle while PID is active (see PID_FUNCTIONAL_RANGE below); 255=full current
#define MAX_BED_POWER 255 // limits duty cycle to bed; 255=full current
#define PREVENT_DANGEROUS_EXTRUDE
#define PREVENT_LENGTHY_EXTRUDE
#define EXTRUDE_MINTEMP 170
#define EXTRUDE_MAXLENGTH (X_MAX_LENGTH+Y_MAX_LENGTH) //prevent extrusion of very large distances.
#define ENDSTOPPULLUPS // Comment this out (using // at the start of the line) to disable the endstop pullup resistors
  #define ENDSTOPPULLUP_XMAX
  #define ENDSTOPPULLUP_YMAX
  #define ENDSTOPPULLUP_ZMAX
  #define ENDSTOPPULLUP_XMIN
  #define ENDSTOPPULLUP_YMIN
  #define ENDSTOPPULLUP_ZMIN
const bool X_MIN_ENDSTOP_INVERTING = false; // set to true to invert the logic of the endstop.
const bool Y_MIN_ENDSTOP_INVERTING = false; // set to true to invert the logic of the endstop.
const bool Z_MIN_ENDSTOP_INVERTING = true; // set to true to invert the logic of the endstop.
const bool X_MAX_ENDSTOP_INVERTING = false; // set to true to invert the logic of the endstop.
const bool Y_MAX_ENDSTOP_INVERTING = false; // set to true to invert the logic of the endstop.
const bool Z_MAX_ENDSTOP_INVERTING = false; // set to true to invert the logic of the endstop.
#if defined(COREXY) && !defined(DISABLE_MAX_ENDSTOPS)
  #define DISABLE_MAX_ENDSTOPS
#endif
#define X_ENABLE_ON 0
#define Y_ENABLE_ON 0
#define Z_ENABLE_ON 0
#define E_ENABLE_ON 0 // For all extruders
#define DISABLE_X false
#define DISABLE_Y false
#define DISABLE_Z false
#define DISABLE_E false // For all extruders
#define DISABLE_INACTIVE_EXTRUDER true //disable only inactive extruders and keep active extruder enabled
#define INVERT_X_DIR true    // for Mendel set to false, for Orca set to true
#define INVERT_Y_DIR false    // for Mendel set to true, for Orca set to false
#define INVERT_Z_DIR true     // for Mendel set to false, for Orca set to true
#define INVERT_E0_DIR false   // for direct drive extruder v9 set to true, for geared extruder set to false
#define INVERT_E1_DIR false    // for direct drive extruder v9 set to true, for geared extruder set to false
#define INVERT_E2_DIR false   // for direct drive extruder v9 set to true, for geared extruder set to false
#define X_HOME_DIR -1
#define Y_HOME_DIR -1
#define Z_HOME_DIR -1
#define min_software_endstops false // If true, axis won't move to coordinates less than HOME_POS.
#define max_software_endstops true  // If true, axis won't move to coordinates greater than the defined lengths below.
#define X_MAX_POS 240
#define X_MIN_POS 0
#define Y_MAX_POS 205
#define Y_MIN_POS 0
#define Z_MAX_POS 50
#define Z_MIN_POS 0
#define X_MAX_LENGTH (X_MAX_POS - X_MIN_POS)
#define Y_MAX_LENGTH (Y_MAX_POS - Y_MIN_POS)
#define Z_MAX_LENGTH (Z_MAX_POS - Z_MIN_POS)
#define Z_PROBE_REPEATABILITY_TEST  // If not commented out, Z-Probe Repeatability test will be included if Auto Bed Leveling is Enabled.
#define MANUAL_X_HOME_POS 0
#define MANUAL_Y_HOME_POS 0
#define MANUAL_Z_HOME_POS 0
#define NUM_AXIS 4 // The axis order in all axis related arrays is X, Y, Z, E
#define HOMING_FEEDRATE {300, 300, 100, 0}  // set the homing speeds (mm/min)
#define Cyclone_XY_Gear_Ratio 21.0/21.0 // Number of tooth (motor/rod)
#define Cyclone_Z_Gear_Ratio 8.0/15.0 // Number of tooth (motor/rod)
#define DEFAULT_AXIS_STEPS_PER_UNIT   {3200.0/(Cyclone_XY_Gear_Ratio*1.25),3200.0/(Cyclone_XY_Gear_Ratio*1.25),3200.0/(Cyclone_Z_Gear_Ratio*1.25),800}  // steps per unit for Cyclone
#define DEFAULT_MAX_FEEDRATE          {5, 5, 2.5, 45}    // (mm/sec)
#define DEFAULT_MAX_ACCELERATION      {1,1,1, 50}    // X, Y, Z, E maximum start speed for accelerated moves. E default values are good for skeinforge 40+, for older versions raise them a lot.
#define DEFAULT_ACCELERATION          2     // X, Y, Z and E max acceleration in mm/s^2 for printing moves
#define DEFAULT_RETRACT_ACCELERATION  200   // X, Y, Z and E max acceleration in mm/s^2 for r retracts
#define DEFAULT_XYJERK                2.5    // (mm/sec)
#define DEFAULT_ZJERK                 2.5    // (mm/sec)
#define DEFAULT_EJERK                 5.0    // (mm/sec)
#define CUSTOM_M_CODES
  #define CUSTOM_M_CODE_SET_Z_PROBE_OFFSET 851
  #define Z_PROBE_OFFSET_RANGE_MIN -15
  #define Z_PROBE_OFFSET_RANGE_MAX -5
#define G0_MAX_FEEDRATE
#define EEPROM_SETTINGS
#define EEPROM_CHITCHAT
#define PLA_PREHEAT_HOTEND_TEMP 180
#define PLA_PREHEAT_HPB_TEMP 70
#define PLA_PREHEAT_FAN_SPEED 255   // Insert Value between 0 and 255
#define ABS_PREHEAT_HOTEND_TEMP 240
#define ABS_PREHEAT_HPB_TEMP 100
#define ABS_PREHEAT_FAN_SPEED 255   // Insert Value between 0 and 255
#define ULTIPANEL  //the UltiPanel as on Thingiverse
#define REPRAP_DISCOUNT_FULL_GRAPHIC_SMART_CONTROLLER
 #define DOGLCD
 #define U8GLIB_ST7920
 #define REPRAP_DISCOUNT_SMART_CONTROLLER
 #define ULTIPANEL
 #define NEWPANEL
  #define SDSUPPORT
  #define ULTRA_LCD
    #define LCD_WIDTH 20
    #define LCD_HEIGHT 5
#  define DEFAULT_LCD_CONTRAST 32
#define SOFT_PWM_SCALE 0
#include "Configuration_adv.h"
#include "thermistortables.h"

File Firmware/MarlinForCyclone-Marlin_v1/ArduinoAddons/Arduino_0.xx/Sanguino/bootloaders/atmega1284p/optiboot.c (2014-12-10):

/**********************************************************/
/* -Wl,-section-start=bootloader=0x1fc00 */
/* Optiboot bootloader for Arduino                        */
/*                                                        */
/* http://optiboot.googlecode.com                         */
/*                                                        */
/* Arduino-maintained version : See README.TXT            */
/* http://code.google.com/p/arduino/                      */
/*                                                        */
/* Heavily optimised bootloader that is faster and        */
/* smaller than the Arduino standard bootloader           */
/*                                                        */
/* Enhancements:                                          */
/*   Fits in 512 bytes, saving 1.5K of code space         */
/*   Background page erasing speeds up programming        */
/*   Higher baud rate speeds up programming               */
/*   Written almost entirely in C                         */
/*   Customisable timeout with accurate timeconstant      */
/*   Optional virtual UART. No hardware UART required.    */
/*   Optional virtual boot partition for devices without. */
/*                                                        */
/* What you lose:                                         */
/*   Implements a skeleton STK500 protocol which is       */
/*     missing several features including EEPROM          */
/*     programming and non-page-aligned writes            */
/*   High baud rate breaks compatibility with standard    */
/*     Arduino flash settings                             */
/*                                                        */
/* Fully supported:                                       */
/*   ATmega168 based devices  (Diecimila etc)             */
/*   ATmega328P based devices (Duemilanove etc)           */
/*                                                        */
/* Alpha test                                             */
/*   ATmega1280 based devices (Arduino Mega)              */
/*                                                        */
/* Work in progress:                                      */
/*   ATmega644P based devices (Sanguino)                  */
/*   ATtiny84 based devices (Luminet)                     */
/*                                                        */
/* Does not support:                                      */
/*   USB based devices (eg. Teensy)                       */
/*                                                        */
/* Assumptions:                                           */
/*   The code makes several assumptions that reduce the   */
/*   code size. They are all true after a hardware reset, */
/*   but may not be true if the bootloader is called by   */
/*   other means or on other hardware.                    */
/*     No interrupts can occur                            */
/*     UART and Timer 1 are set to their reset state      */
/*     SP points to RAMEND                                */
/*                                                        */
/* Code builds on code, libraries and optimisations from: */
/*   stk500boot.c          by Jason P. Kyle               */
/*   Arduino bootloader    http://arduino.cc              */
/*   Spiff's 1K bootloader http://spiffie.org/know/arduino_1k_bootloader/bootloader.shtml */
/*   avr-libc project      http://nongnu.org/avr-libc     */
/*   Adaboot               http://www.ladyada.net/library/arduino/bootloader.html */
/*   AVR305                Atmel Application Note         */
/*                                                        */
/* This program is free software; you can redistribute it */
/* and/or modify it under the terms of the GNU General    */
/* Public License as published by the Free Software       */
/* Foundation; either version 2 of the License, or        */
/* (at your option) any later version.                    */
/*                                                        */
/* This program is distributed in the hope that it will   */
/* be useful, but WITHOUT ANY WARRANTY; without even the  */
/* implied warranty of MERCHANTABILITY or FITNESS FOR A   */
/* PARTICULAR PURPOSE.  See the GNU General Public        */
/* License for more details.                              */
/*                                                        */
/* You should have received a copy of the GNU General     */
/* Public License along with this program; if not, write  */
/* to the Free Software Foundation, Inc.,                 */
/* 59 Temple Place, Suite 330, Boston, MA  02111-1307 USA */
/*                                                        */
/* Licence can be viewed at                               */
/* http://www.fsf.org/licenses/gpl.txt                    */
/*                                                        */
/**********************************************************/


/**********************************************************/
/*                                                        */
/* Optional defines:                                      */
/*                                                        */
/**********************************************************/
/*                                                        */
/* BIG_BOOT:                                              */
/* Build a 1k bootloader, not 512 bytes. This turns on    */
/* extra functionality.                                   */
/*                                                        */
/* BAUD_RATE:                                             */
/* Set bootloader baud rate.                              */
/*                                                        */
/* LUDICROUS_SPEED:                                       */
/* 230400 baud :-)                                        */
/*                                                        */
/* SOFT_UART:                                             */
/* Use AVR305 soft-UART instead of hardware UART.         */
/*                                                        */
/* LED_START_FLASHES:                                     */
/* Number of LED flashes on bootup.                       */
/*                                                        */
/* LED_DATA_FLASH:                                        */
/* Flash LED when transferring data. For boards without   */
/* TX or RX LEDs, or for people who like blinky lights.   */
/*                                                        */
/* SUPPORT_EEPROM:                                        */
/* Support reading and writing from EEPROM. This is not   */
/* used by Arduino, so off by default.                    */
/*                                                        */
/* TIMEOUT_MS:                                            */
/* Bootloader timeout period, in milliseconds.            */
/* 500,1000,2000,4000,8000 supported.                     */
/*                                                        */
/**********************************************************/


/**********************************************************/
/* Version Numbers!                                       */
/*                                                        */
/* Arduino Optiboot now includes this Version number in   */
/* the source and object code.                            */
/*                                                        */
/* Version 3 was released as zip from the optiboot        */
/*  repository and was distributed with Arduino 0022.     */
/* Version 4 starts with the arduino repository commit    */
/*  that brought the arduino repository up-to-date with   */
/* the optiboot source tree changes since v3.             */
/*                                                        */
/**********************************************************/

/**********************************************************/
/* Edit History:                                          */
/*                                                        */
/* Jan 2012:                                              */
/* 4.5 WestfW: fix NRWW value for m1284.                  */
/* 4.4 WestfW: use attribute OS_main instead of naked for */
/*             main().  This allows optimizations that we */
/*             count on, which are prohibited in naked    */
/*             functions due to PR42240.  (keeps us less  */
/*             than 512 bytes when compiler is gcc4.5     */
/*             (code from 4.3.2 remains the same.)        */
/* 4.4 WestfW and Maniacbug:  Add m1284 support.  This    */
/*             does not change the 328 binary, so the     */
/*             version number didn't change either. (?)   */
/* June 2011:                                             */
/* 4.4 WestfW: remove automatic soft_uart detect (didn't  */
/*             know what it was doing or why.)  Added a   */
/*             check of the calculated BRG value instead. */
/*             Version stays 4.4; existing binaries are   */
/*             not changed.                               */
/* 4.4 WestfW: add initialization of address to keep      */
/*             the compiler happy.  Change SC'ed targets. */
/*             Return the SW version via READ PARAM       */
/* 4.3 WestfW: catch framing errors in getch(), so that   */
/*             AVRISP works without HW kludges.           */
/*  http://code.google.com/p/arduino/issues/detail?id=368n*/
/* 4.2 WestfW: reduce code size, fix timeouts, change     */
/*             verifySpace to use WDT instead of appstart */
/* 4.1 WestfW: put version number in binary.              */
/**********************************************************/

#define OPTIBOOT_MAJVER 4
#define OPTIBOOT_MINVER 5

#define MAKESTR(a) #a
#define MAKEVER(a, b) MAKESTR(a*256+b)

asm("  .section .version\n"
    "optiboot_version:  .word " MAKEVER(OPTIBOOT_MAJVER, OPTIBOOT_MINVER) "\n"
    "  .section .text\n");


#include <inttypes.h>
#include <avr/io.h>
#include <avr/pgmspace.h>

// <avr/boot.h> uses sts instructions, but this version uses out instructions
// This saves cycles and program memory.
#include "boot.h"


// We don't use <avr/wdt.h> as those routines have interrupt overhead we don't need.

#include "pin_defs.h"
#include "stk500.h"

#ifndef LED_START_FLASHES
#define LED_START_FLASHES 0
#endif

#ifdef LUDICROUS_SPEED
#define BAUD_RATE 230400L
#endif

/* set the UART baud rate defaults */
#ifndef BAUD_RATE
#if F_CPU >= 8000000L
#define BAUD_RATE   115200L // Highest rate Avrdude win32 will support
#elsif F_CPU >= 1000000L
#define BAUD_RATE   9600L   // 19200 also supported, but with significant error
#elsif F_CPU >= 128000L
#define BAUD_RATE   4800L   // Good for 128kHz internal RC
#else
#define BAUD_RATE 1200L     // Good even at 32768Hz
#endif
#endif

#if 0
/* Switch in soft UART for hard baud rates */
/*
 * I don't understand what this was supposed to accomplish, where the
 * constant "280" came from, or why automatically (and perhaps unexpectedly)
 * switching to a soft uart is a good thing, so I'm undoing this in favor
 * of a range check using the same calc used to config the BRG...
 */
#if (F_CPU/BAUD_RATE) > 280 // > 57600 for 16MHz
#ifndef SOFT_UART
#define SOFT_UART
#endif
#endif
#else // 0
#if (F_CPU + BAUD_RATE * 4L) / (BAUD_RATE * 8L) - 1 > 250
#error Unachievable baud rate (too slow) BAUD_RATE 
#endif // baud rate slow check
#if (F_CPU + BAUD_RATE * 4L) / (BAUD_RATE * 8L) - 1 < 3
#error Unachievable baud rate (too fast) BAUD_RATE 
#endif // baud rate fastn check
#endif

/* Watchdog settings */
#define WATCHDOG_OFF    (0)
#define WATCHDOG_16MS   (_BV(WDE))
#define WATCHDOG_32MS   (_BV(WDP0) | _BV(WDE))
#define WATCHDOG_64MS   (_BV(WDP1) | _BV(WDE))
#define WATCHDOG_125MS  (_BV(WDP1) | _BV(WDP0) | _BV(WDE))
#define WATCHDOG_250MS  (_BV(WDP2) | _BV(WDE))
#define WATCHDOG_500MS  (_BV(WDP2) | _BV(WDP0) | _BV(WDE))
#define WATCHDOG_1S     (_BV(WDP2) | _BV(WDP1) | _BV(WDE))
#define WATCHDOG_2S     (_BV(WDP2) | _BV(WDP1) | _BV(WDP0) | _BV(WDE))
#ifndef __AVR_ATmega8__
#define WATCHDOG_4S     (_BV(WDP3) | _BV(WDE))
#define WATCHDOG_8S     (_BV(WDP3) | _BV(WDP0) | _BV(WDE))
#endif

/* Function Prototypes */
/* The main function is in init9, which removes the interrupt vector table */
/* we don't need. It is also 'naked', which means the compiler does not    */
/* generate any entry or exit code itself. */
int main(void) __attribute__ ((OS_main)) __attribute__ ((section (".init9")));
void putch(char);
uint8_t getch(void);
static inline void getNch(uint8_t); /* "static inline" is a compiler hint to reduce code size */
void verifySpace();
static inline void flash_led(uint8_t);
uint8_t getLen();
static inline void watchdogReset();
void watchdogConfig(uint8_t x);
#ifdef SOFT_UART
void uartDelay() __attribute__ ((naked));
#endif
void appStart() __attribute__ ((naked));

/*
 * NRWW memory
 * Addresses below NRWW (Non-Read-While-Write) can be programmed while
 * continuing to run code from flash, slightly speeding up programming
 * time.  Beware that Atmel data sheets specify this as a WORD address,
 * while optiboot will be comparing against a 16-bit byte address.  This
 * means that on a part with 128kB of memory, the upper part of the lower
 * 64k will get NRWW processing as well, even though it doesn't need it.
 * That's OK.  In fact, you can disable the overlapping processing for
 * a part entirely by setting NRWWSTART to zero.  This reduces code
 * space a bit, at the expense of being slightly slower, overall.
 *
 * RAMSTART should be self-explanatory.  It's bigger on parts with a
 * lot of peripheral registers.
 */
#if defined(__AVR_ATmega168__)
#define RAMSTART (0x100)
#define NRWWSTART (0x3800)
#elif defined(__AVR_ATmega328P__)
#define RAMSTART (0x100)
#define NRWWSTART (0x7000)
#elif defined (__AVR_ATmega644P__)
#define RAMSTART (0x100)
#define NRWWSTART (0xE000)
#elif defined (__AVR_ATmega1284P__)
#define RAMSTART (0x100)
#define NRWWSTART (0xE000)
#elif defined(__AVR_ATtiny84__)
#define RAMSTART (0x100)
#define NRWWSTART (0x0000)
#elif defined(__AVR_ATmega1280__)
#define RAMSTART (0x200)
#define NRWWSTART (0xE000)
#elif defined(__AVR_ATmega8__) || defined(__AVR_ATmega88__)
#define RAMSTART (0x100)
#define NRWWSTART (0x1800)
#endif

/* C zero initialises all global variables. However, that requires */
/* These definitions are NOT zero initialised, but that doesn't matter */
/* This allows us to drop the zero init code, saving us memory */
#define buff    ((uint8_t*)(RAMSTART))
#ifdef VIRTUAL_BOOT_PARTITION
#define rstVect (*(uint16_t*)(RAMSTART+SPM_PAGESIZE*2+4))
#define wdtVect (*(uint16_t*)(RAMSTART+SPM_PAGESIZE*2+6))
#endif

/* main program starts here */
int main(void) {
  uint8_t ch;

  /*
   * Making these local and in registers prevents the need for initializing
   * them, and also saves space because code no longer stores to memory.
   * (initializing address keeps the compiler happy, but isn't really
   *  necessary, and uses 4 bytes of flash.)
   */
  register uint16_t address = 0;
  register uint8_t  length;

  // After the zero init loop, this is the first code to run.
  //
  // This code makes the following assumptions:
  //  No interrupts will execute
  //  SP points to RAMEND
  //  r1 contains zero
  //
  // If not, uncomment the following instructions:
  // cli();
  asm volatile ("clr __zero_reg__");
#ifdef __AVR_ATmega8__
  SP=RAMEND;  // This is done by hardware reset
#endif

  // Adaboot no-wait mod
  ch = MCUSR;
  MCUSR = 0;
  if (!(ch & _BV(EXTRF))) appStart();

#if LED_START_FLASHES > 0
  // Set up Timer 1 for timeout counter
  TCCR1B = _BV(CS12) | _BV(CS10); // div 1024
#endif
#ifndef SOFT_UART
#ifdef __AVR_ATmega8__
  UCSRA = _BV(U2X); //Double speed mode USART
  UCSRB = _BV(RXEN) | _BV(TXEN);  // enable Rx & Tx
  UCSRC = _BV(URSEL) | _BV(UCSZ1) | _BV(UCSZ0);  // config USART; 8N1
  UBRRL = (uint8_t)( (F_CPU + BAUD_RATE * 4L) / (BAUD_RATE * 8L) - 1 );
#else
  UCSR0A = _BV(U2X0); //Double speed mode USART0
  UCSR0B = _BV(RXEN0) | _BV(TXEN0);
  UCSR0C = _BV(UCSZ00) | _BV(UCSZ01);
  UBRR0L = (uint8_t)( (F_CPU + BAUD_RATE * 4L) / (BAUD_RATE * 8L) - 1 );
#endif
#endif

  // Set up watchdog to trigger after 500ms
  watchdogConfig(WATCHDOG_1S);

  /* Set LED pin as output */
  LED_DDR |= _BV(LED);

#ifdef SOFT_UART
  /* Set TX pin as output */
  UART_DDR |= _BV(UART_TX_BIT);
#endif

#if LED_START_FLASHES > 0
  /* Flash onboard LED to signal entering of bootloader */
  flash_led(LED_START_FLASHES * 2);
#endif

  /* Forever loop */
  for (;;) {
    /* get character from UART */
    ch = getch();

    if(ch == STK_GET_PARAMETER) {
      unsigned char which = getch();
      verifySpace();
      if (which == 0x82) {
        /*
         * Send optiboot version as "minor SW version"
         */
        putch(OPTIBOOT_MINVER);
      } else if (which == 0x81) {
          putch(OPTIBOOT_MAJVER);
      } else {
        /*
         * GET PARAMETER returns a generic 0x03 reply for
         * other parameters - enough to keep Avrdude happy
         */
        putch(0x03);
      }
    }
    else if(ch == STK_SET_DEVICE) {
      // SET DEVICE is ignored
      getNch(20);
    }
    else if(ch == STK_SET_DEVICE_EXT) {
      // SET DEVICE EXT is ignored
      getNch(5);
    }
    else if(ch == STK_LOAD_ADDRESS) {
      // LOAD ADDRESS
      uint16_t newAddress;
      newAddress = getch();
      newAddress = (newAddress & 0xff) | (getch() << 8);
#ifdef RAMPZ
      // Transfer top bit to RAMPZ
      RAMPZ = (newAddress & 0x8000) ? 1 : 0;
#endif
      newAddress += newAddress; // Convert from word address to byte address
      address = newAddress;
      verifySpace();
    }
    else if(ch == STK_UNIVERSAL) {
      // UNIVERSAL command is ignored
      getNch(4);
      putch(0x00);
    }
    /* Write memory, length is big endian and is in bytes */
    else if(ch == STK_PROG_PAGE) {
      // PROGRAM PAGE - we support flash programming only, not EEPROM
      uint8_t *bufPtr;
      uint16_t addrPtr;

      getch();                  /* getlen() */
      length = getch();
      getch();

      // If we are in RWW section, immediately start page erase
      if (address < NRWWSTART) __boot_page_erase_short((uint16_t)(void*)address);

      // While that is going on, read in page contents
      bufPtr = buff;
      do *bufPtr++ = getch();
      while (--length);

      // If we are in NRWW section, page erase has to be delayed until now.
      // Todo: Take RAMPZ into account
      if (address >= NRWWSTART) __boot_page_erase_short((uint16_t)(void*)address);

      // Read command terminator, start reply
      verifySpace();

      // If only a partial page is to be programmed, the erase might not be complete.
      // So check that here
      boot_spm_busy_wait();

#ifdef VIRTUAL_BOOT_PARTITION
      if ((uint16_t)(void*)address == 0) {
        // This is the reset vector page. We need to live-patch the code so the
        // bootloader runs.
        //
        // Move RESET vector to WDT vector
        uint16_t vect = buff[0] | (buff[1]<<8);
        rstVect = vect;
        wdtVect = buff[8] | (buff[9]<<8);
        vect -= 4; // Instruction is a relative jump (rjmp), so recalculate.
        buff[8] = vect & 0xff;
        buff[9] = vect >> 8;

        // Add jump to bootloader at RESET vector
        buff[0] = 0x7f;
        buff[1] = 0xce; // rjmp 0x1d00 instruction
      }
#endif

      // Copy buffer into programming buffer
      bufPtr = buff;
      addrPtr = (uint16_t)(void*)address;
      ch = SPM_PAGESIZE / 2;
      do {
        uint16_t a;
        a = *bufPtr++;
        a |= (*bufPtr++) << 8;
        __boot_page_fill_short((uint16_t)(void*)addrPtr,a);
        addrPtr += 2;
      } while (--ch);

      // Write from programming buffer
      __boot_page_write_short((uint16_t)(void*)address);
      boot_spm_busy_wait();

#if defined(RWWSRE)
      // Reenable read access to flash
      boot_rww_enable();
#endif

    }
    /* Read memory block mode, length is big endian.  */
    else if(ch == STK_READ_PAGE) {
      // READ PAGE - we only read flash
      getch();                  /* getlen() */
      length = getch();
      getch();

      verifySpace();
#ifdef VIRTUAL_BOOT_PARTITION
      do {
        // Undo vector patch in bottom page so verify passes
        if (address == 0)       ch=rstVect & 0xff;
        else if (address == 1)  ch=rstVect >> 8;
        else if (address == 8)  ch=wdtVect & 0xff;
        else if (address == 9) ch=wdtVect >> 8;
        else ch = pgm_read_byte_near(address);
        address++;
        putch(ch);
      } while (--length);
#else
#ifdef RAMPZ
// Since RAMPZ should already be set, we need to use EPLM directly.
//      do putch(pgm_read_byte_near(address++));
//      while (--length);
      do {
        uint8_t result;
        __asm__ ("elpm %0,Z\n":"=r"(result):"z"(address));
        putch(result);
        address++;
      }
      while (--length);
#else
      do putch(pgm_read_byte_near(address++));
      while (--length);
#endif
#endif
    }

    /* Get device signature bytes  */
    else if(ch == STK_READ_SIGN) {
      // READ SIGN - return what Avrdude wants to hear
      verifySpace();
      putch(SIGNATURE_0);
      putch(SIGNATURE_1);
      putch(SIGNATURE_2);
    }
    else if (ch == STK_LEAVE_PROGMODE) { /* 'Q' */
      // Adaboot no-wait mod
      watchdogConfig(WATCHDOG_16MS);
      verifySpace();
    }
    else {
      // This covers the response to commands like STK_ENTER_PROGMODE
      verifySpace();
    }
    putch(STK_OK);
  }
}
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

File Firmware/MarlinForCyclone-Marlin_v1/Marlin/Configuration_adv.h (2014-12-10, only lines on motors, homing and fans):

#define CONTROLLERFAN_PIN -1 //Pin used for the fan to cool controller (-1 to disable)
#define EXTRUDER_0_AUTO_FAN_PIN   -1
#define EXTRUDER_1_AUTO_FAN_PIN   -1
#define EXTRUDER_2_AUTO_FAN_PIN   -1
#define X_HOME_RETRACT_MM 2
#define Y_HOME_RETRACT_MM 2
#define Z_HOME_RETRACT_MM 0.5
#define MICROSTEP1 LOW,LOW
#define MICROSTEP2 HIGH,LOW
#define MICROSTEP4 LOW,HIGH
#define MICROSTEP8 HIGH,HIGH
#define MICROSTEP16 HIGH,HIGH
#define MICROSTEP_MODES {16,16,16,16,16} // [1,2,4,8,16]
#define DIGIPOT_MOTOR_CURRENT {135,135,135,135,135} // Values 0-255 (RAMBO 135 = ~0.75A, 185 = ~1A)
#define DIGIPOT_I2C_MOTOR_CURRENTS {1.0, 1.0, 1.0, 1.0, 1.0, 1.0, 1.0, 1.0}

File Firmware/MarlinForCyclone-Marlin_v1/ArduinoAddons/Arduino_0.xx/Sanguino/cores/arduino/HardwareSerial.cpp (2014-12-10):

/*
  HardwareSerial.cpp - Hardware serial library for Wiring
  Copyright (c) 2006 Nicholas Zambetti.  All right reserved.

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
  Modified 23 November 2006 by David A. Mellis
  Modified 28 September 2010 by Mark Sproul
*/

#include <stdlib.h>
#include <stdio.h>
#include <string.h>
#include <inttypes.h>
#include "wiring.h"
#include "wiring_private.h"

// this next line disables the entire HardwareSerial.cpp, 
// this is so I can support Attiny series and any other chip without a uart
#if defined(UBRRH) || defined(UBRR0H) || defined(UBRR1H) || defined(UBRR2H) || defined(UBRR3H)

#include "HardwareSerial.h"

// Define constants and variables for buffering incoming serial data.  We're
// using a ring buffer (I think), in which rx_buffer_head is the index of the
// location to which to write the next incoming character and rx_buffer_tail
// is the index of the location from which to read.
#if (RAMEND < 1000)
  #define RX_BUFFER_SIZE 32
#else
  #define RX_BUFFER_SIZE 128
#endif

struct ring_buffer
{
  unsigned char buffer[RX_BUFFER_SIZE];
  int head;
  int tail;
};

#if defined(UBRRH) || defined(UBRR0H)
  ring_buffer rx_buffer  =  { { 0 }, 0, 0 };
#endif
#if defined(UBRR1H)
  ring_buffer rx_buffer1  =  { { 0 }, 0, 0 };
#endif
#if defined(UBRR2H)
  ring_buffer rx_buffer2  =  { { 0 }, 0, 0 };
#endif
#if defined(UBRR3H)
  ring_buffer rx_buffer3  =  { { 0 }, 0, 0 };
#endif

inline void store_char(unsigned char c, ring_buffer *rx_buffer)
{
  int i = (unsigned int)(rx_buffer->head + 1) % RX_BUFFER_SIZE;

  // if we should be storing the received character into the location
  // just before the tail (meaning that the head would advance to the
  // current location of the tail), we're about to overflow the buffer
  // and so we don't write the character or advance the head.
  if (i != rx_buffer->tail) {
    rx_buffer->buffer[rx_buffer->head] = c;
    rx_buffer->head = i;
  }
}

#if defined(USART_RX_vect)
  SIGNAL(USART_RX_vect)
  {
  #if defined(UDR0)
    unsigned char c  =  UDR0;
  #elif defined(UDR)
    unsigned char c  =  UDR;  //  atmega8535
  #else
    #error UDR not defined
  #endif
    store_char(c, &rx_buffer);
  }
#elif defined(SIG_USART0_RECV) && defined(UDR0)
  SIGNAL(SIG_USART0_RECV)
  {
    unsigned char c  =  UDR0;
    store_char(c, &rx_buffer);
  }
#elif defined(SIG_UART0_RECV) && defined(UDR0)
  SIGNAL(SIG_UART0_RECV)
  {
    unsigned char c  =  UDR0;
    store_char(c, &rx_buffer);
  }
//#elif defined(SIG_USART_RECV)
#elif defined(USART0_RX_vect)
  // fixed by Mark Sproul this is on the 644/644p
  //SIGNAL(SIG_USART_RECV)
  SIGNAL(USART0_RX_vect)
  {
  #if defined(UDR0)
    unsigned char c  =  UDR0;
  #elif defined(UDR)
    unsigned char c  =  UDR;  //  atmega8, atmega32
  #else
    #error UDR not defined
  #endif
    store_char(c, &rx_buffer);
  }
#elif defined(SIG_UART_RECV)
  // this is for atmega8
  SIGNAL(SIG_UART_RECV)
  {
  #if defined(UDR0)
    unsigned char c  =  UDR0;  //  atmega645
  #elif defined(UDR)
    unsigned char c  =  UDR;  //  atmega8
  #endif
    store_char(c, &rx_buffer);
  }
#elif defined(USBCON)
  #warning No interrupt handler for usart 0
  #warning Serial(0) is on USB interface
#else
  #error No interrupt handler for usart 0
#endif

//#if defined(SIG_USART1_RECV)
#if defined(USART1_RX_vect)
  //SIGNAL(SIG_USART1_RECV)
  SIGNAL(USART1_RX_vect)
  {
    unsigned char c = UDR1;
    store_char(c, &rx_buffer1);
  }
#elif defined(SIG_USART1_RECV)
  #error SIG_USART1_RECV
#endif

#if defined(USART2_RX_vect) && defined(UDR2)
  SIGNAL(USART2_RX_vect)
  {
    unsigned char c = UDR2;
    store_char(c, &rx_buffer2);
  }
#elif defined(SIG_USART2_RECV)
  #error SIG_USART2_RECV
#endif
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

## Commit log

2014-11-30 Screw Size customization
    Moved the screw size settings to the Cyclone.scad file for better screw size customization
    [Cyclone.scad]
2014-12-08 custom configuration files
    added output files, stl's and gcode for Replicator 2 with custom config
    file for 12 x 12 machine
    [Cyclone.scad, Ylm8uuHolder.stl, btm.stl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]
2014-12-08 Moved end stop module/added parameters to config
    Moved the module for the endstop holder to separate file, added
    parameters to configuration files to accomodate different types of end
    stop switches.
    [Cycl_endstop_holder.scad, Cyclone.scad]
2014-12-09 moving X axis towards center of y axis travel
    shifting the x axis to the center
    [Cycl_X_frames.scad, Cyclone.scad, XleftFrame.stl]
2014-12-09 misc design changes - dev
    misc changes
    [rightframe180.stl]
2014-12-10 Added support for an alternitive z-carriage
    as described in
    https://github.com/carlosgs/Cyclone-PCB-Factory/issues/32#issuecomment-66381271
    [Cycl_X_carriage_alt.scad, Cycl_Z_carriage_alt.scad, Cyclone.scad]
2014-12-10 cleanup file structure to v2 format
    moved output files to new directory tree
    [Cycl_X_frames_alt.scad, Cycl_endstop_alt.scad, XleftFrame.stl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]
2014-12-11 configure to allow end stop switch alterations
    [Cycl_Endstop_holder.scad, Cycl_Endstop_holder_alt.scad, Cycl_X_frames_alt.scad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]
2014-12-11 change config files
    [Cyclone.scad]
2014-12-11 made endstop holder render switchable in config file
    [Cycl_Endstop_holder.scad, Cycl_Endstop_holder_alt.scad, Cycl_X_frames.scad]
2014-12-11 tweaking last x frame mounting hole
    subtracted 6 for rear hole and screw in translate
    [Cycl_X_frames.scad, rightframe180.stl]
2014-12-15 Alternative Z nut concept
    Can be enabled in the Default_config.h by settings alt_Z_nut = true
    [Cycl_X_carriage.scad]
2014-12-16 machine config changes
    [Cycl_Z_carriage.scad, Cyclone.scad, rightframe180.stl]
2014-12-22 misc tweaks for testing
    [Configuration.h]
